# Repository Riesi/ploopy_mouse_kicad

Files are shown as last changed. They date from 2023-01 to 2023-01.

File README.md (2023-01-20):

# DISCLAIMER
## How was this ported to KiCAD?

The heavy lifting was done by the [altium2kicad](https://github.com/thesourcerer8/altium2kicad) converter. If you like this port do consider donating to the converter project!

After that I took the converted files and pruned unnecessary ones. Then I fixed the schematics by replacing the broken symbols with either existing ones or created custom symbols.
All components have been named as they appear in the PCB to allow for relinking of the footprints with the `Update Schematic from PCB` option in eeschema.
Finally I fixed the DRC errors generated in the PCB (default design rule settings). This meant fixing the broken edge cut lines, due to the converter creating non closed and not fully connected lines. It also sprinkled some edge cut dots over the lines, which was not that easy to find!

### Can I use this port instead of the main project?

I don't think anything speaks against using this KiCAD version. But be warned that I haven't produced a PCB with it myself! So things could be broken!
If you just want a working PCB you should use Gerber files produced from the original version instead.

If you want to help verifying the design please do so!

### Current Validation

Validation has been done with the `Gerbv` tool, which allows to compare two Gerber files and show their difference/overlap.
The files used for the validation are located in `./gerber_diff_view`. You can run the `diff_gerber.sh` to verify some of the Gerber files yourself. Be sure to generate the KiCAD Gerber in the following path `hardware/electronics/QMKMouse/gerber/` before running the script. There are also comparison shots of some layers in which the white corresponds to KiCAD, green to Altium and purple to the matching XOR of both.

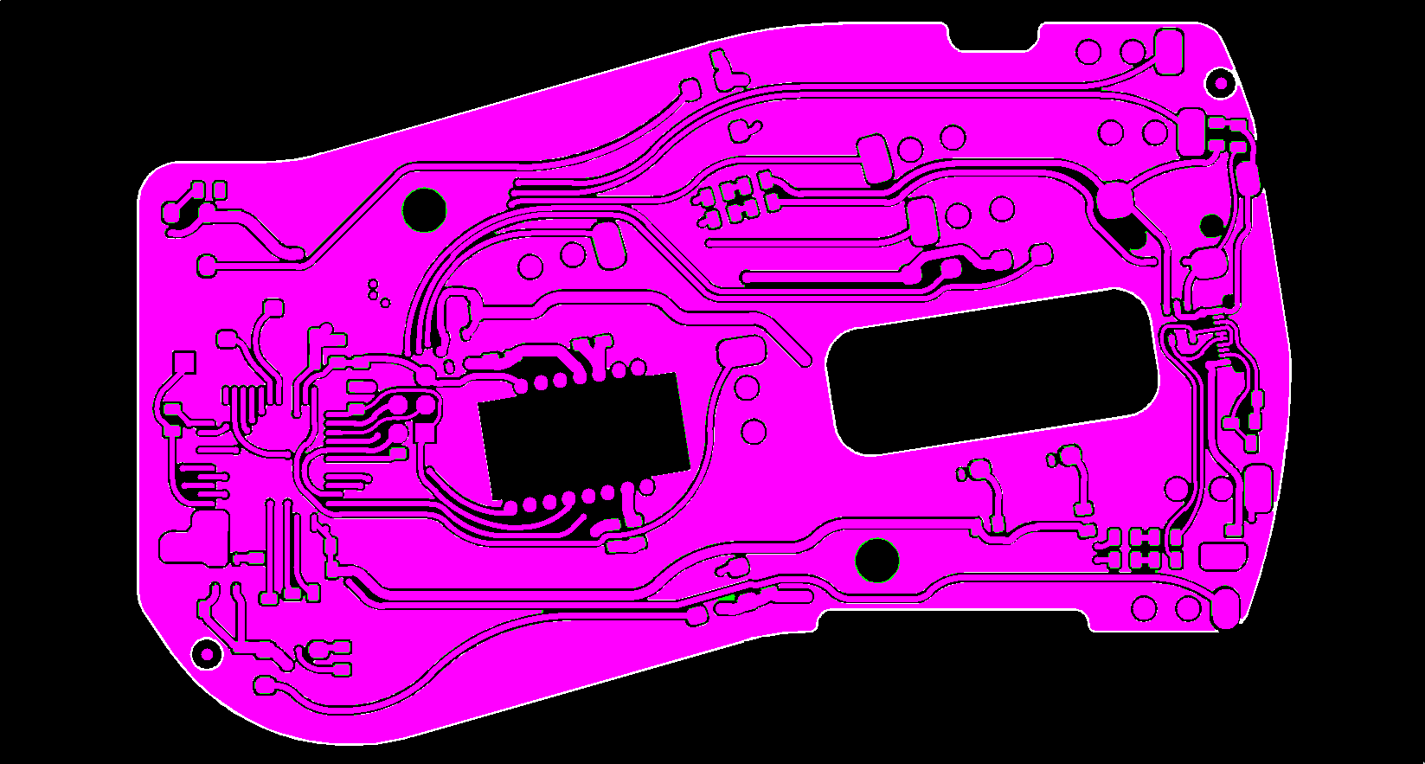
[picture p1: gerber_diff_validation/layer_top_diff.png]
Diff of top layers


#### Labels:

Text is different due to fonts.
Drawings look correct.

#### Layers:

Only minimal difference due to difference in clearance to the border cut and filling algorithm.
KiCAD version has a bit more portions filled. This should not be an issue.

#### Edge Cuts:

Match.

#### Drill:
Drill holes look correct.
Mismatch on some holes that are not plated in the fabricated PCB, but Altium files still contain them as plated.
Should be no problem.

#### Drill Maps:
No drill mapped to optical sensor in KiCAD, but this should not be an issue.

#### Masks:

Match.

#### Pastes:

Match.

# The Ploopy Mouse

By some stroke of luck, you've made your way here. The Ploopy Mouse. Your life will never be the same.

This repository contains all of the design and production files necessary to make a Ploopy Mouse. We've also included some kick-ass documentation in the Wiki on how to get it made, assemble it, and program it.

What are you waiting for? Your new life awaits.

## QMK?!

Kits bought from the [Ploopy store](https://ploopy.co/product-category/mouse/) come with QMK preloaded. Check out the Wiki for instructions on how to load new firmware onto your device. (It's super easy!)

The firmware hex file that ships with all Mice is included in this repository as well, as `ploopyco_mouse_via.hex`. The hex was built with QMK version 0.11.1.

## Under what license is this released?

Everything in this repository is released under OHL CERN v2-S. Check the LICENSE.md file for full license text.

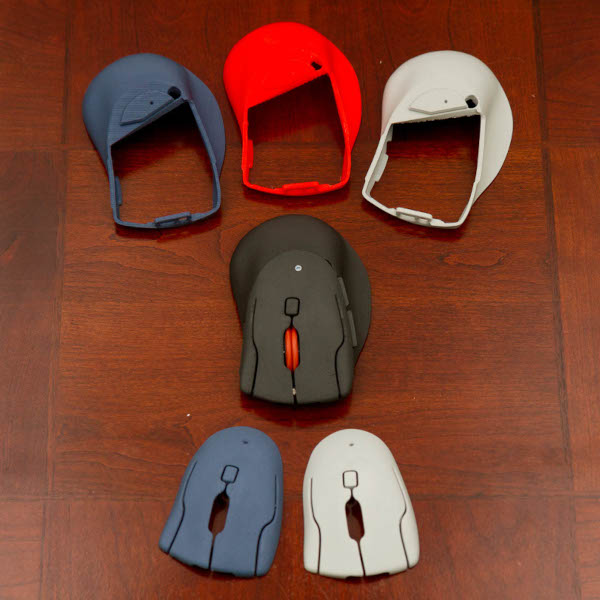
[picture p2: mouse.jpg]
The Ploopy Mouse


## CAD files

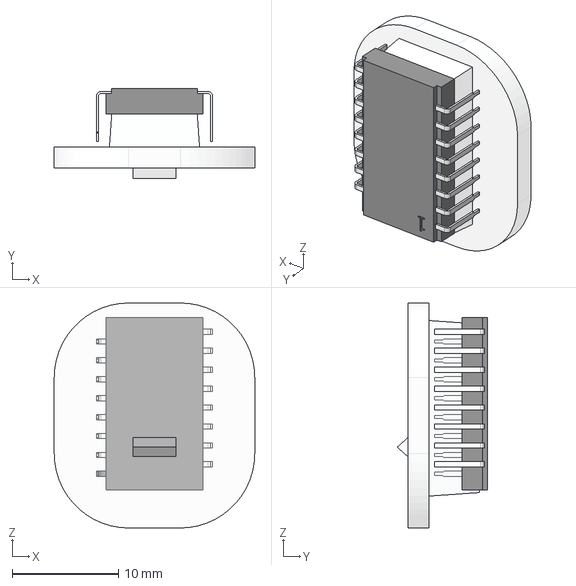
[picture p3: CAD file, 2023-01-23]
hardware/electronics/QMKMouse/ALTIUM_EMBEDDED_MODELS/PMW3360-LM19-LSI-Assembly.stp
18.8 x 8.50 x 21.1 mm
LM19-LSI
PMW3360DM-T2QU

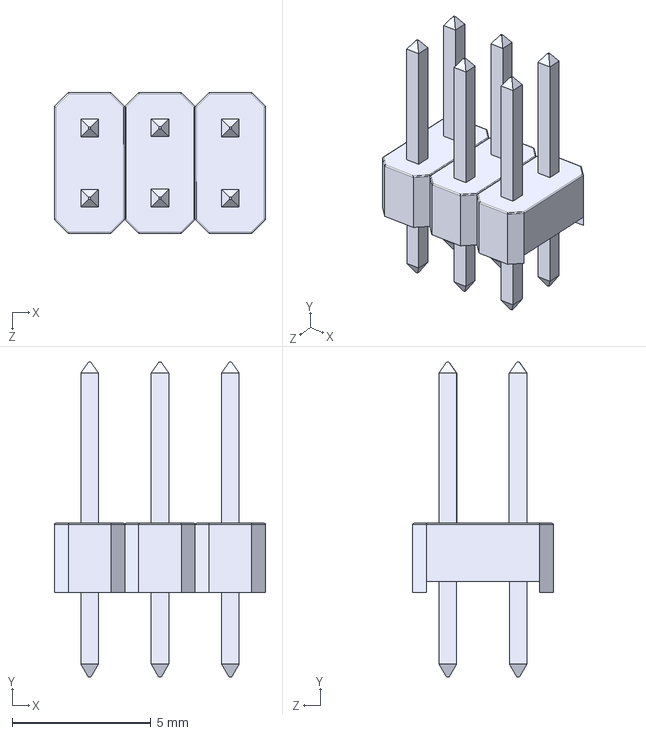
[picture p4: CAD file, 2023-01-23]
hardware/electronics/QMKMouse/ALTIUM_EMBEDDED_MODELS/PR(E,P)C003DAAN-RC.stp
7.62 x 11.4 x 5.08 mm
Dual TH with end bump format x 3

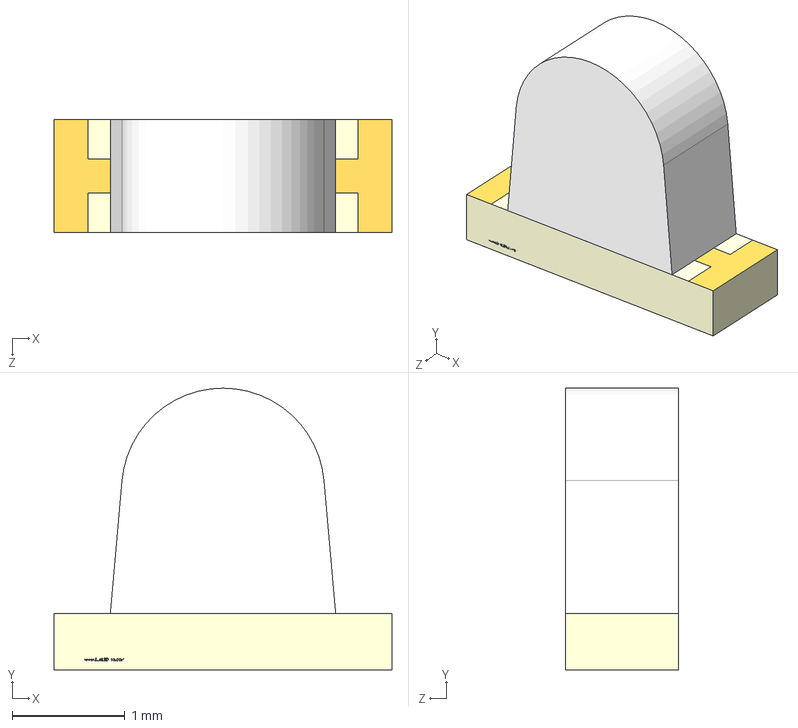
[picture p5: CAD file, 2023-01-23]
hardware/electronics/QMKMouse/ALTIUM_EMBEDDED_MODELS/XZxx56x-1.step
3.00 x 2.50 x 1.00 mm

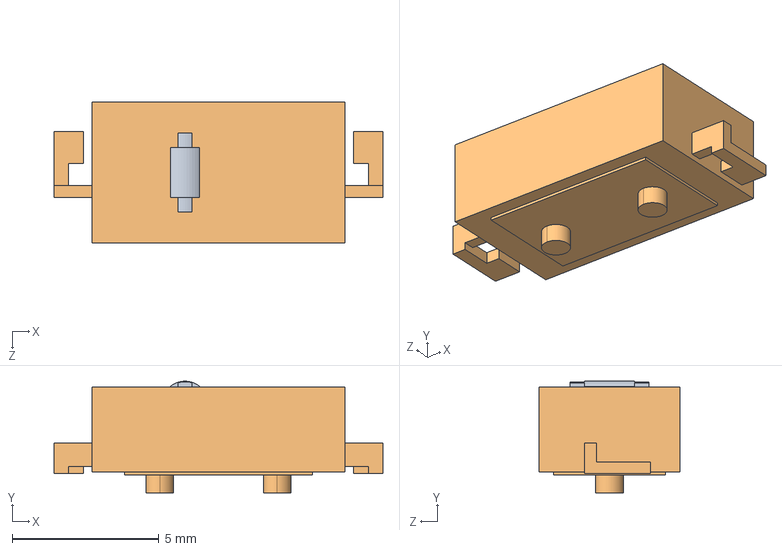
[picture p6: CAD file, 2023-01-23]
hardware/electronics/QMKMouse/ALTIUM_EMBEDDED_MODELS/D2LS_21.step
11.2 x 3.80 x 4.80 mm
D2LS_21_BUTTON
D2LS_21_BASE

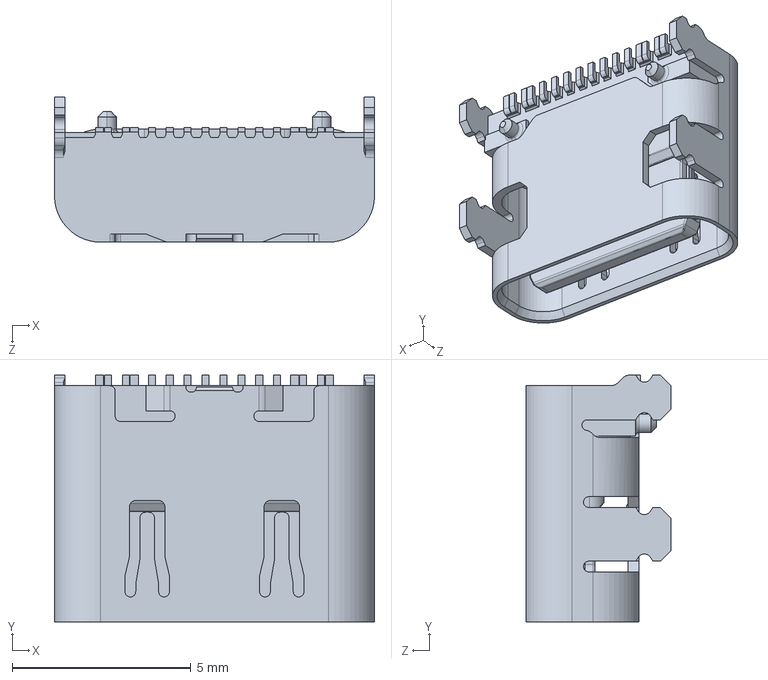
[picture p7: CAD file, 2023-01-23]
hardware/electronics/QMKMouse/ALTIUM_EMBEDDED_MODELS/K3D-DX07S016JA1-V1_JAE_Proprietary.STEP
8.94 x 6.90 x 4.06 mm

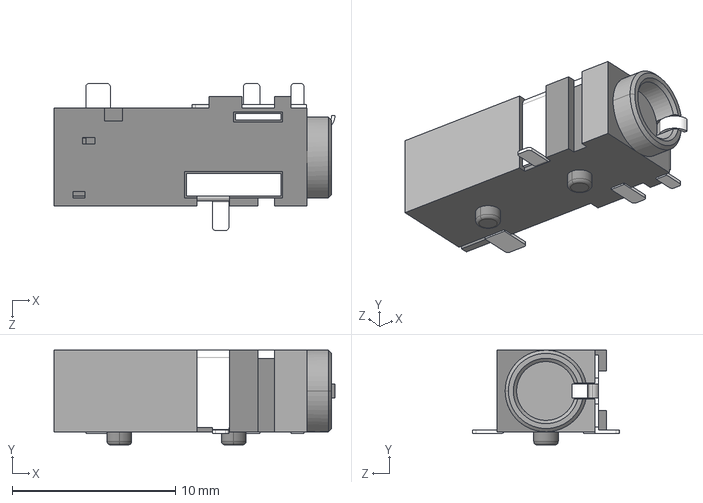
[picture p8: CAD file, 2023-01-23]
hardware/electronics/QMKMouse/ALTIUM_EMBEDDED_MODELS/CUI_DEVICES_SJ-43514-SMT-TR.step
17.2 x 5.80 x 9.00 mm

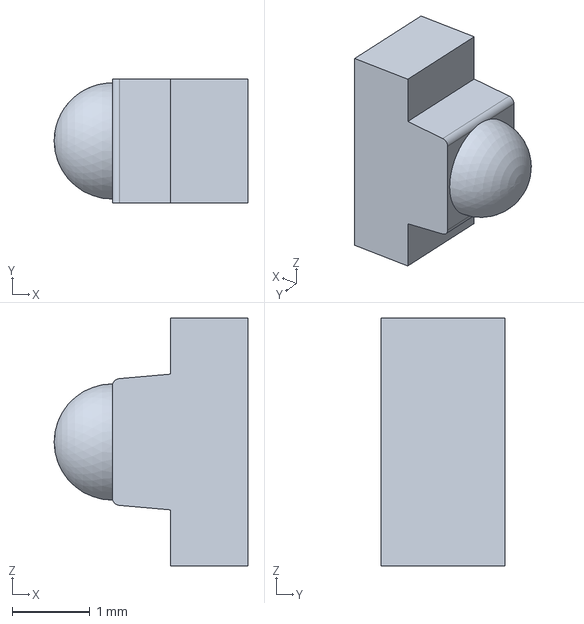
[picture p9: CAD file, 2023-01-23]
hardware/electronics/QMKMouse/ALTIUM_EMBEDDED_MODELS/PT26-51B-TR8.stp
2.50 x 1.60 x 3.20 mm

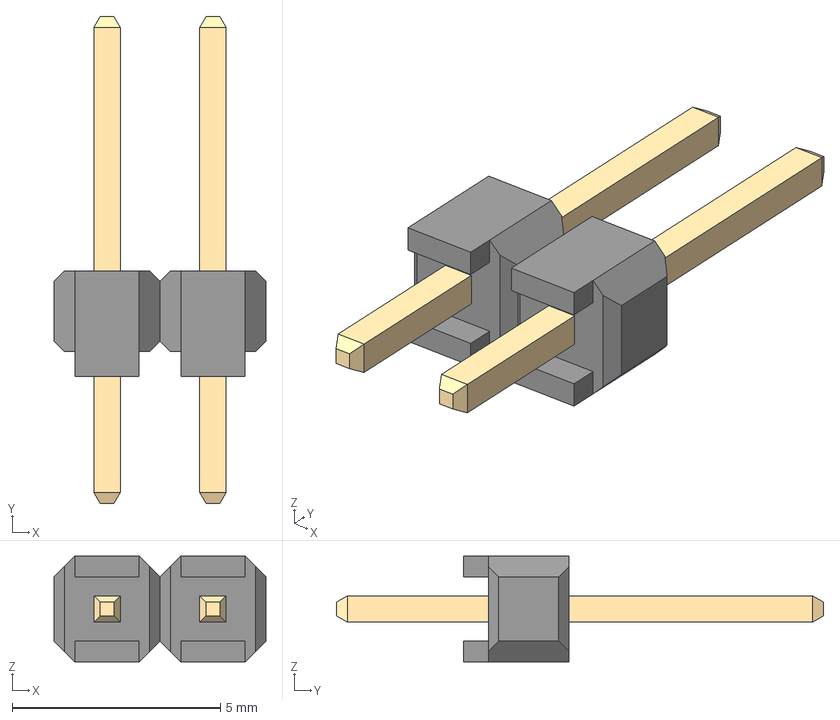
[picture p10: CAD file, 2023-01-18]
hardware/electronics/QMKMouse/ALTIUM_EMBEDDED_MODELS/m20-9990245_asm.stp
5.08 x 11.7 x 2.54 mm
M20-999-MOULD
M20-999-PIN x 2

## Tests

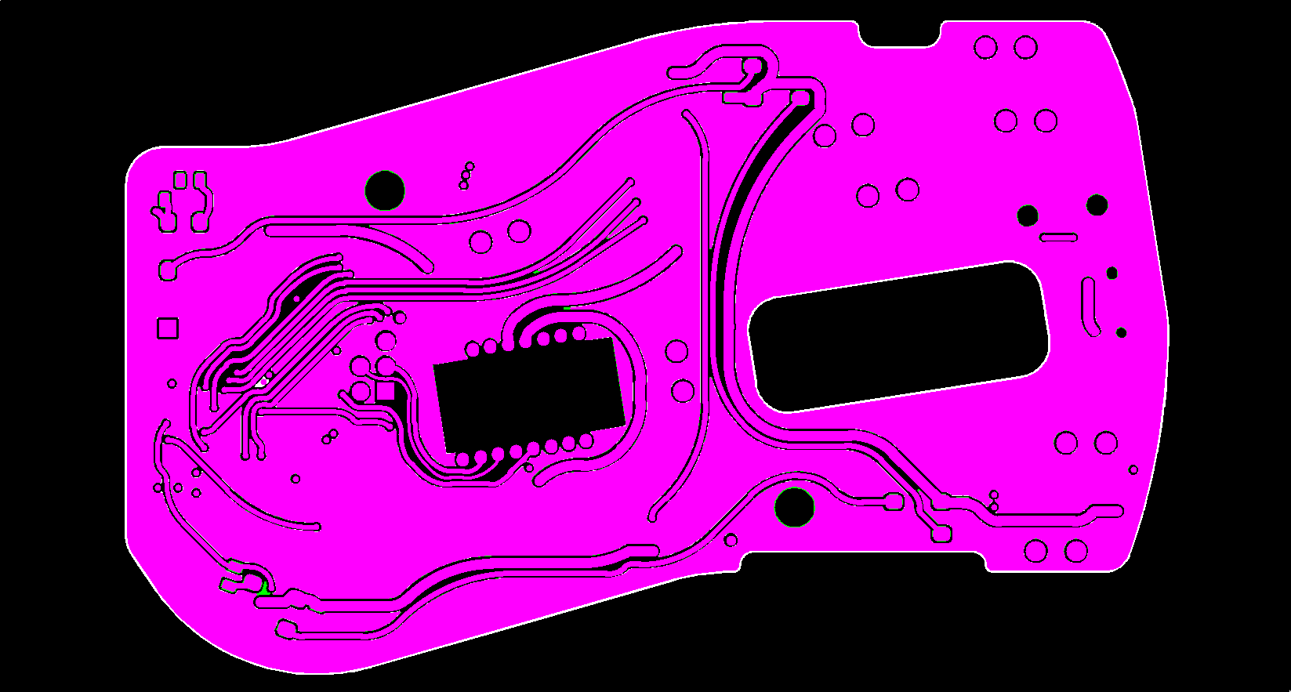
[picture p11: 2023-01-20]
gerber_diff_validation/layer_bot_diff.png

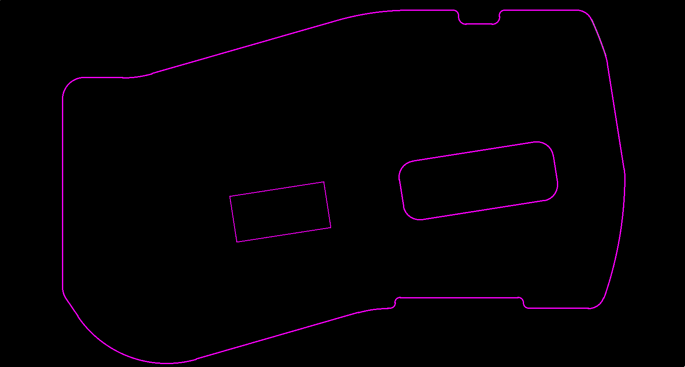
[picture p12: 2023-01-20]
gerber_diff_validation/edge_cuts_diff.png

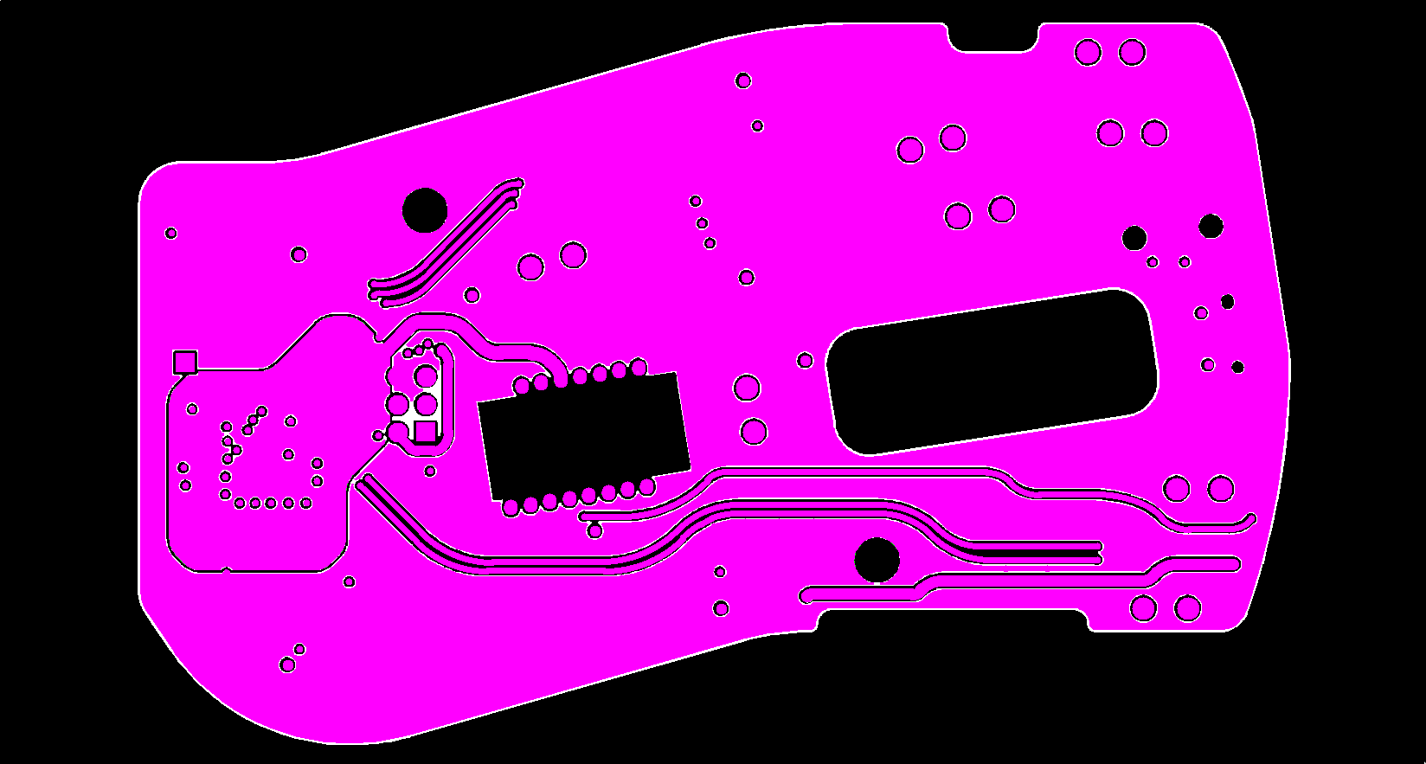
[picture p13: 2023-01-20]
gerber_diff_validation/layer_2_diff.png

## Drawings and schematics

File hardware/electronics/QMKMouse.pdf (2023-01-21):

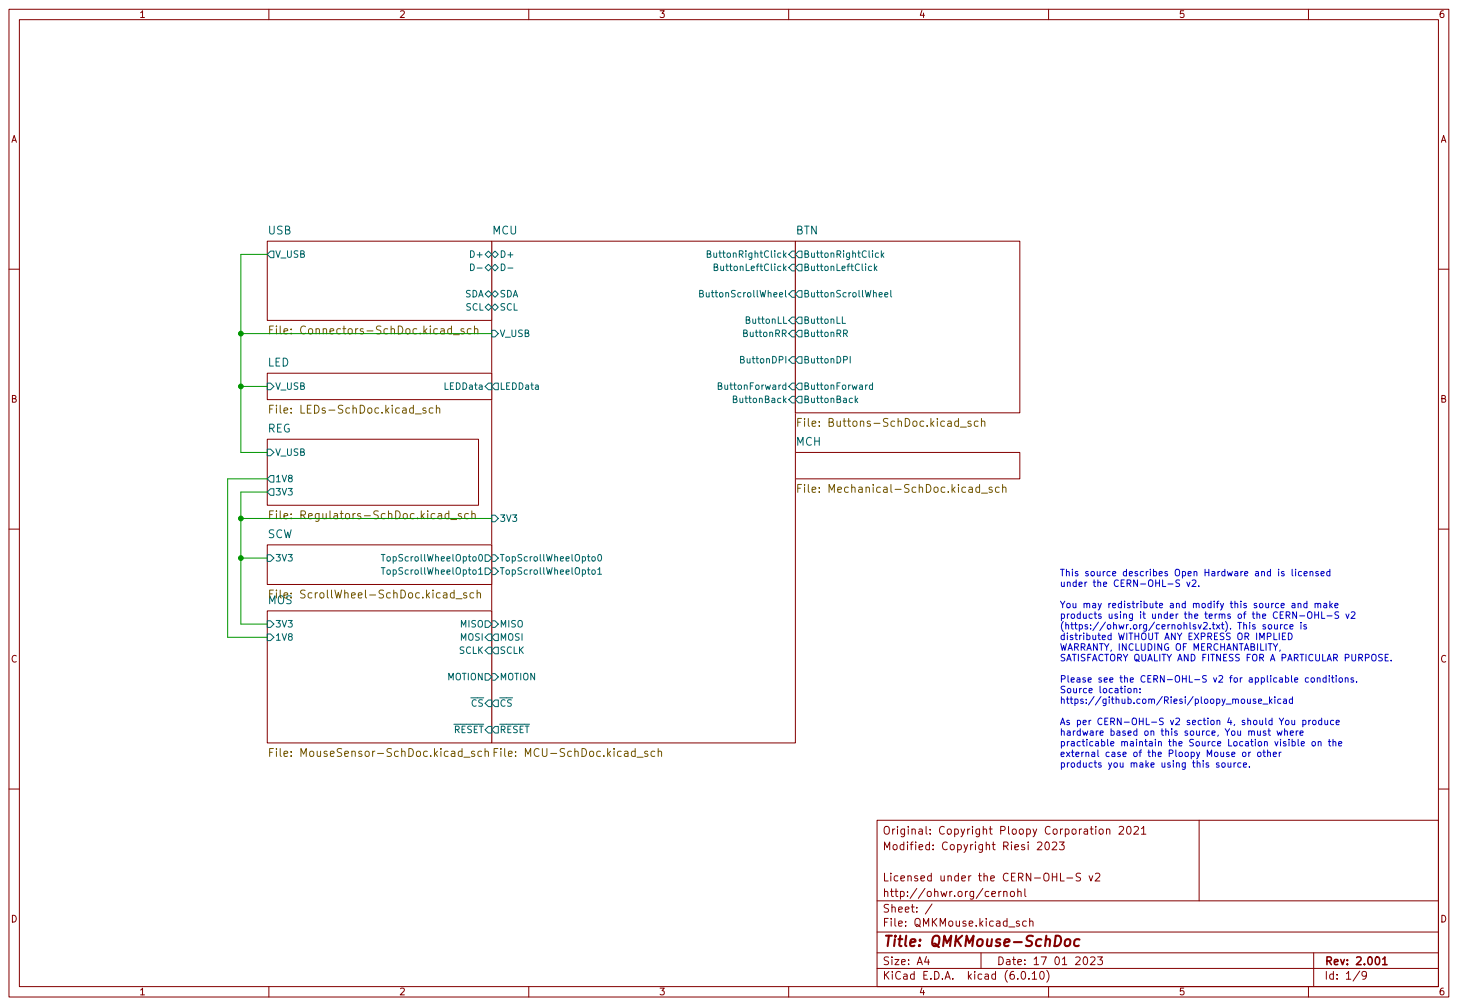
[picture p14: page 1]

ButtonLL BTN
ButtonRightClick ButtonLeftClick ButtonBack ButtonForward ButtonScrollWheel ButtonDPI ButtonRR

File: Buttons-SchDoc.kicad_sch
Licensed under the CERN-OHL-S v2 MCH

This source describes Open Hardware and is licensed under the CERN-OHL-S v2. You may redistribute and modify this source and make

products using it under the terms of the CERN-OHL-S v2
(https://ohwr.org/cernohlsv2.txt). This source is distributed WITHOUT ANY EXPRESS OR IMPLIED WARRANTY, INCLUDING OF MERCHANTABILITY, SATISFACTORY QUALITY AND FITNESS FOR A PARTICULAR PURPOSE. Please see the CERN-OHL-S v2 for applicable conditions. Source location: https://github.com/Riesi/ploopy_mouse_kicad

As per CERN-OHL-S v2 section 4, should You produce hardware based on this source, You must where practicable maintain the Source Location visible on the

external case of the Ploopy Mouse or other
products you make using this source.

Original: Copyright Ploopy Corporation 2021
Modified: Copyright Riesi 2023

File: QMKMouse.kicad_sch Sheet: / http://ohwr.org/cernohl

Id: 1/9 Title: QMKMouse-SchDoc

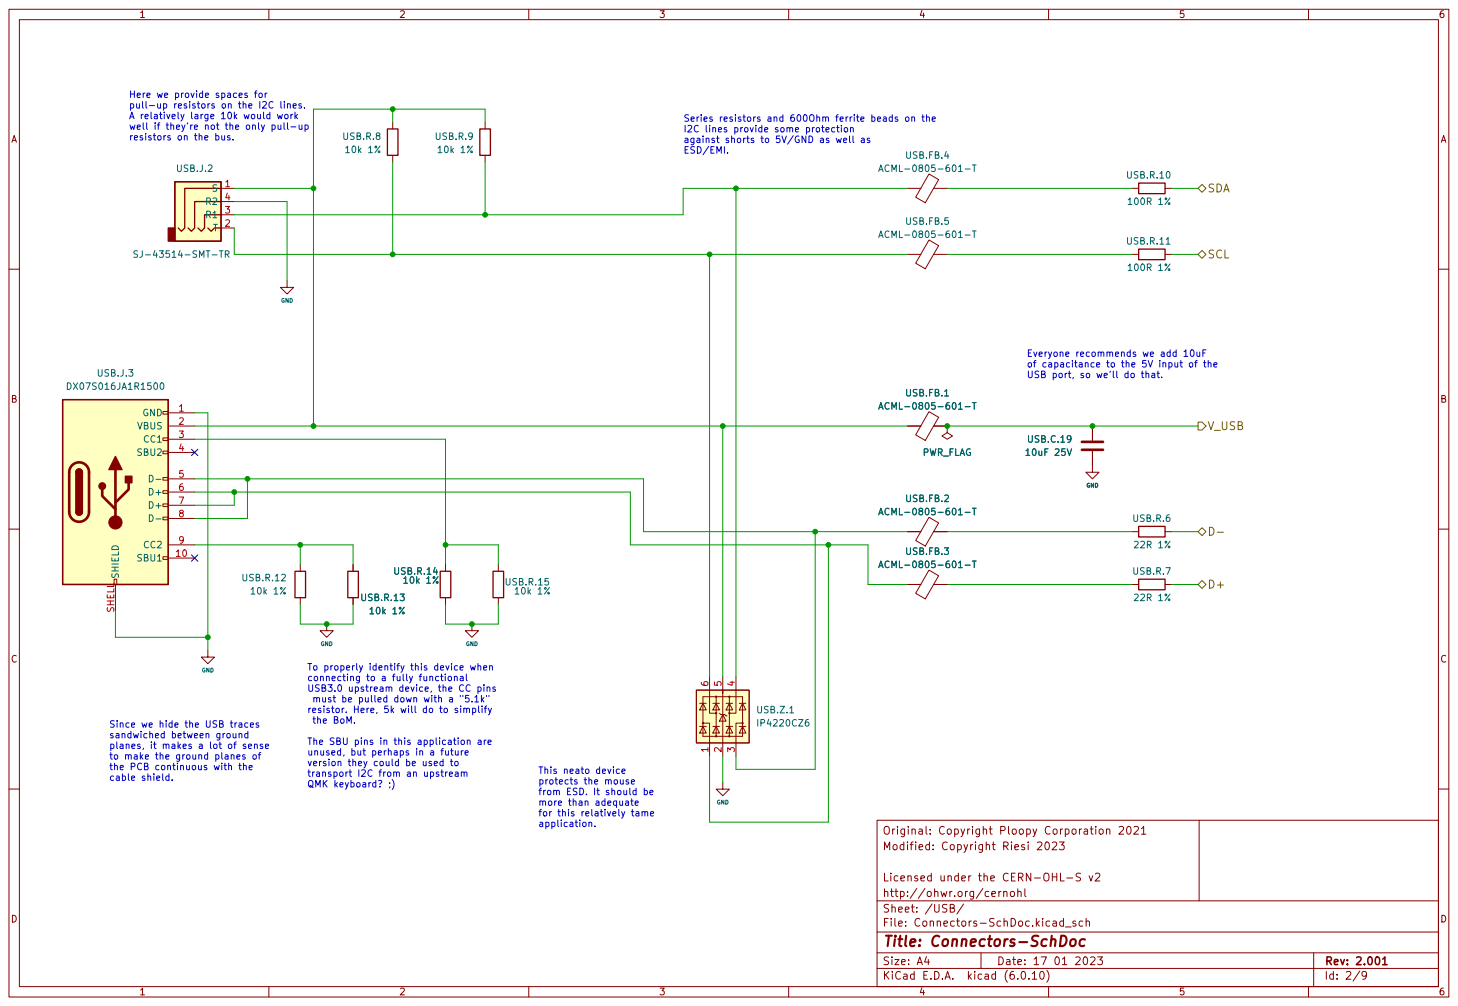
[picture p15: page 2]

against shorts to 5V/GND as well as ESD/EMI. Here we provide spaces for
pull-up resistors on the I2C lines.
A relatively large 10k would work

Series resistors and 600Ohm ferrite beads on the
I2C lines provide some protection

SCL D+D- Everyone recommends we add 10uF

of capacitance to the 5V input of the

USB port, so we'll do that. This neato device protects the mouse

USB.FB.1 ACML-0805-601-T USB.R.13

GND USB.FB.3 ACML-0805-601-T USB.FB.2 ACML-0805-601-T PWR_FLAG

10uF 25V USB.FB.3 ACML-0805-601-T USB.FB.2 ACML-0805-601-T PWR_FLAG

Licensed under the CERN-OHL-S v2 USB.R.12

To properly identify this device when
connecting to a fully functional
USB3.0 upstream device, the CC pins
must be pulled down with a "5.1k"
resistor. Here, 5k will do to simplify
the BoM. The SBU pins in this application are

QMK keyboard? ;) Since we hide the USB traces sandwiched between ground

planes, it makes a lot of sense
to make the ground planes of
the PCB continuous with the cable shield.

unused, but perhaps in a future
version they could be used to
transport I2C from an upstream

from ESD. It should be more than adequate

for this relatively tame
application.

Original: Copyright Ploopy Corporation 2021
Modified: Copyright Riesi 2023

File: Connectors-SchDoc.kicad_sch Sheet: /USB/ http://ohwr.org/cernohl

Id: 2/9 Title: Connectors-SchDoc

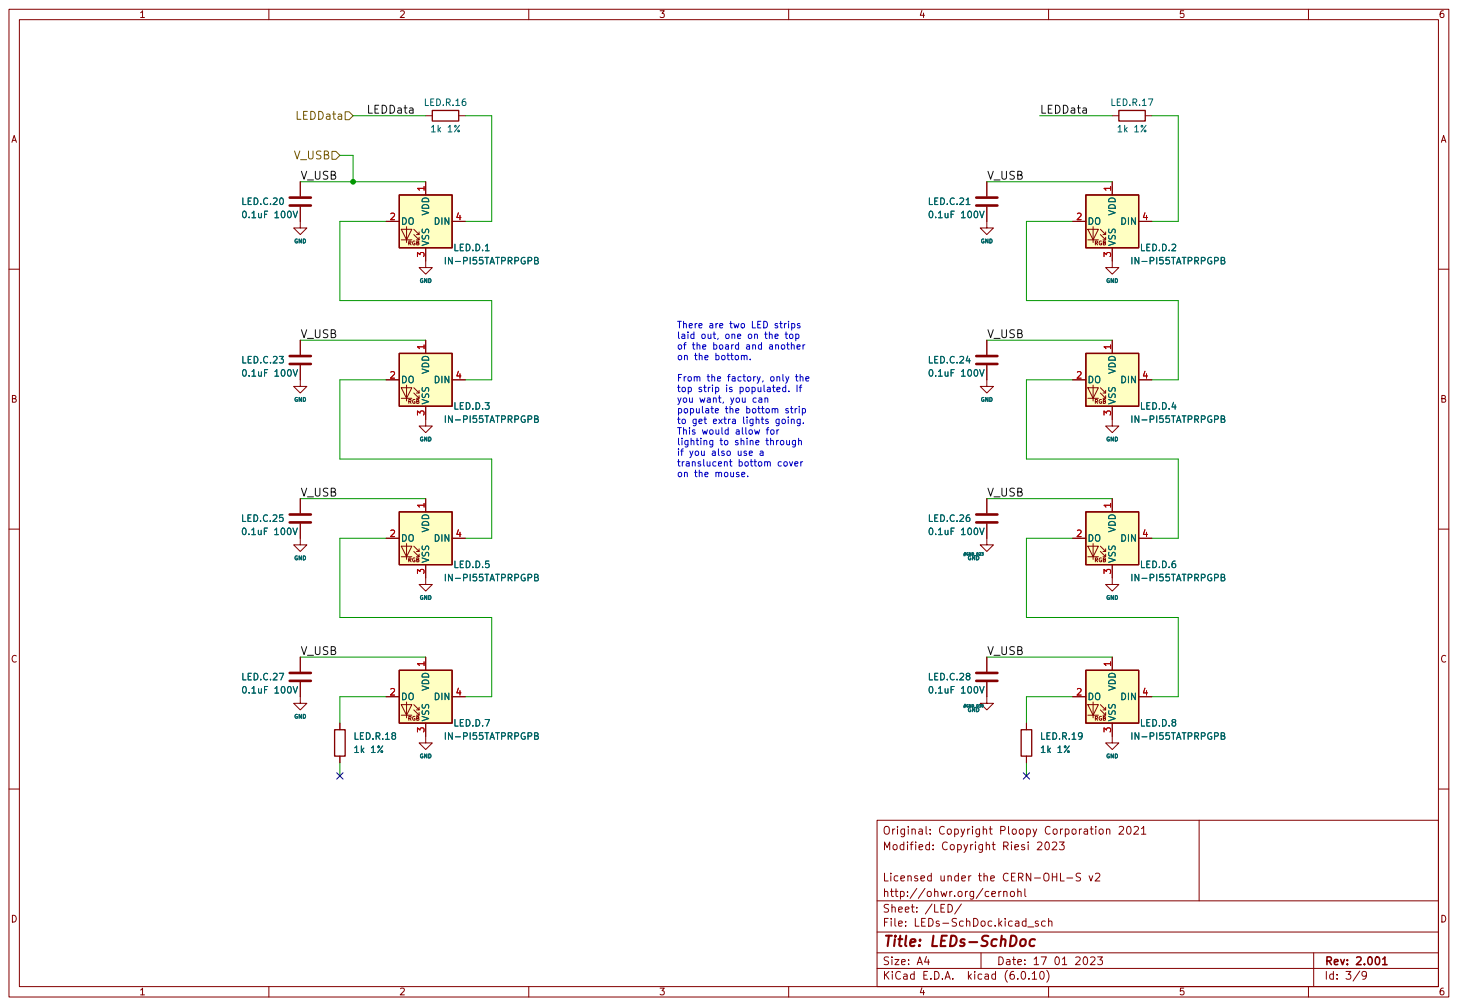
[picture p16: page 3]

There are two LED strips
laid out, one on the top of the board and another on the bottom. From the factory, only the

top strip is populated. If you want, you can populate the bottom strip

to get extra lights going. This would allow for

lighting to shine through
if you also use a

Original: Copyright Ploopy Corporation 2021
Modified: Copyright Riesi 2023

Licensed under the CERN-OHL-S v2
File: LEDs-SchDoc.kicad_sch Sheet: /LED/ http://ohwr.org/cernohl

Id: 3/9 Title: LEDs-SchDoc

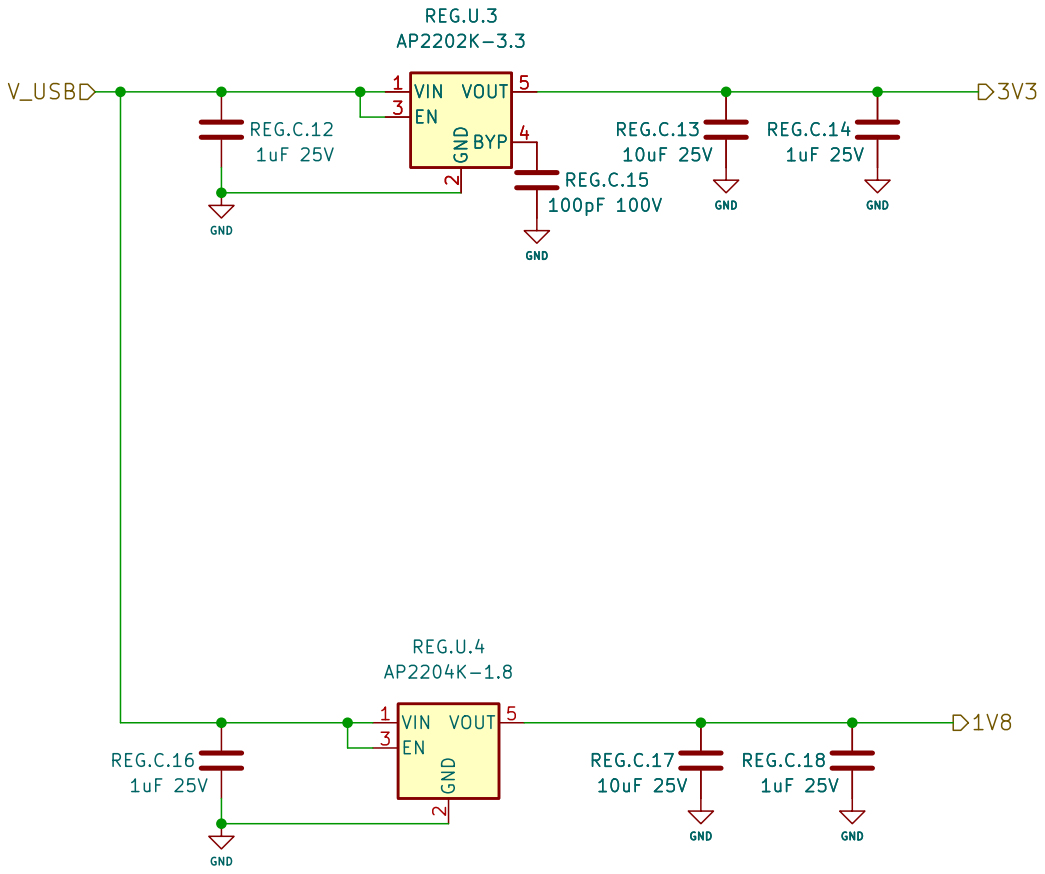
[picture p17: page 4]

2 EN 3 BYP 4 VOUT 5 REG.U.3 AP2202K-3.3 REG.C.15
GND REG.C.17

2 EN 3 VOUT 5 REG.U.4 AP2204K-1.8 REG.C.17

Original: Copyright Ploopy Corporation 2021
Modified: Copyright Riesi 2023

Licensed under the CERN-OHL-S v2
File: Regulators-SchDoc.kicad_sch Sheet: /REG/ http://ohwr.org/cernohl

Id: 4/9 Title: Regulators-SchDoc

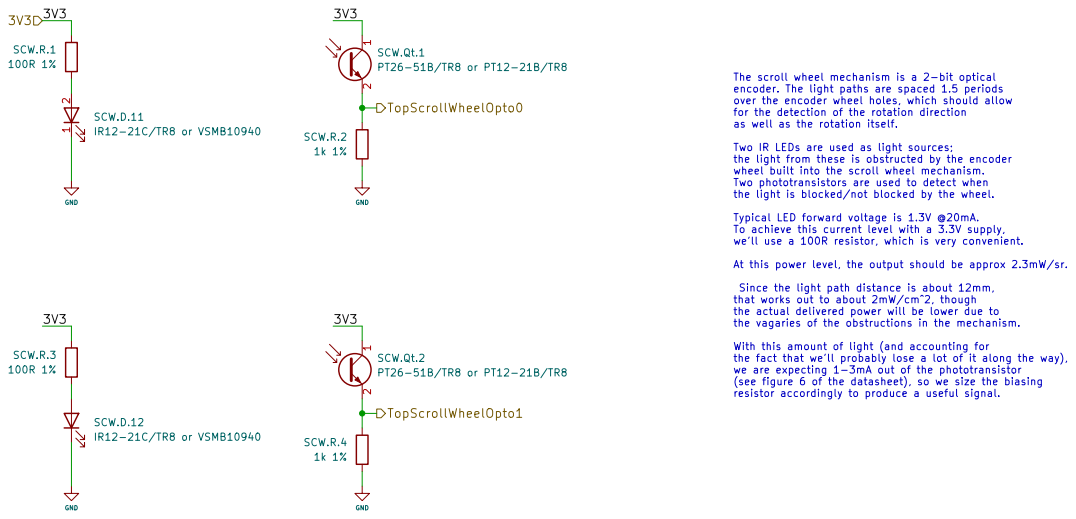
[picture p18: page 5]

1 2 SCW.Qt.1 PT26-51B/TR8 or PT12-21B/TR8 SCW.D.12

The scroll wheel mechanism is a 2-bit optical
encoder. The light paths are spaced 1.5 periods over the encoder wheel holes, which should allow

for the detection of the rotation direction as well as the rotation itself. Two IR LEDs are used as light sources;

the light from these is obstructed by the encoder wheel built into the scroll wheel mechanism. Two phototransistors are used to detect when

the light is blocked/not blocked by the wheel.

Typical LED forward voltage is 1.3V @20mA.
To achieve this current level with a 3.3V supply,
we'll use a 100R resistor, which is very convenient.

At this power level, the output should be approx 2.3mW/sr.

Since the light path distance is about 12mm,
that works out to about 2mW/cm^2, though
the actual delivered power will be lower due to
the vagaries of the obstructions in the mechanism.

With this amount of light (and accounting for
the fact that we'll probably lose a lot of it along the way),
we are expecting 1-3mA out of the phototransistor
(see figure 6 of the datasheet), so we size the biasing
resistor accordingly to produce a useful signal.
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

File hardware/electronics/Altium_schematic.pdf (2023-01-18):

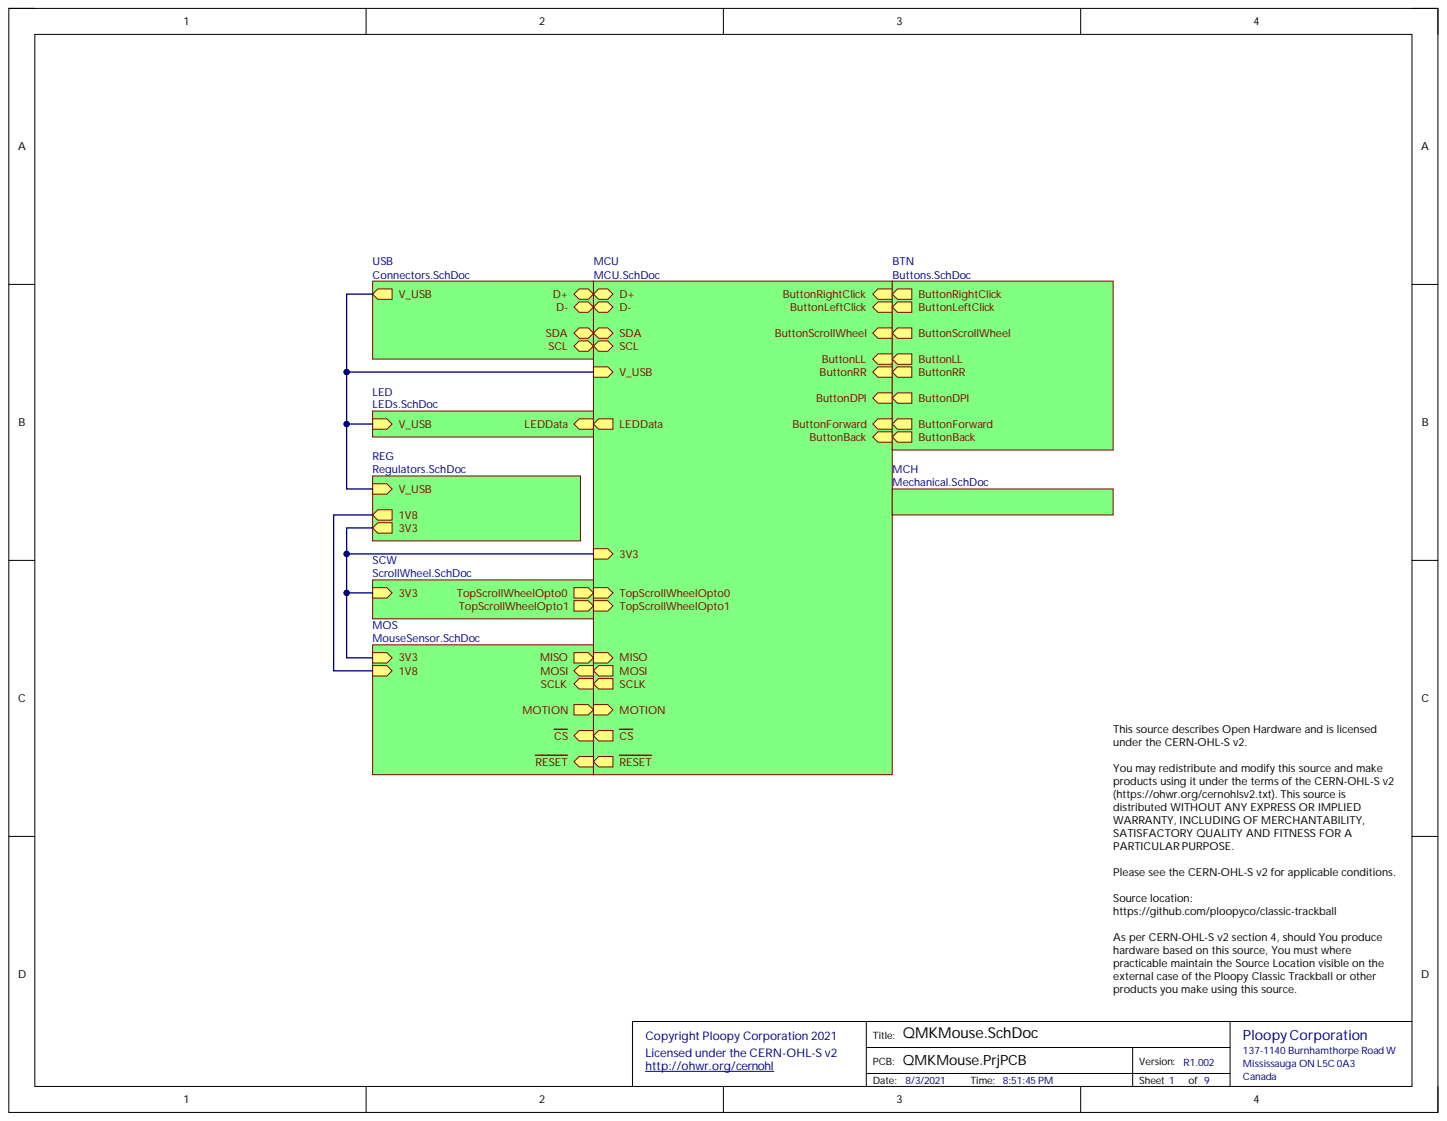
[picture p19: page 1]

This source describes Open Hardware and is licensed
under the CERN-OHL-S v2.

You may redistribute and modify this source and make
products using it under the terms of the CERN-OHL-S v2
(https://ohwr.org/cernohlsv2.txt). This source is
distributed WITHOUT ANY EXPRESS OR IMPLIED
WARRANTY, INCLUDING OF MERCHANTABILITY,
SATISFACTORY QUALITY AND FITNESS FOR A
PARTICULAR PURPOSE.

Please see the CERN-OHL-S v2 for applicable conditions.

Source location:
https://github.com/ploopyco/classic-trackball

As per CERN-OHL-S v2 section 4, should You produce
hardware based on this source, You must where
practicable maintain the Source Location visible on the
external case of the Ploopy Classic Trackball or other
products you make using this source.

Copyright Ploopy Corporation 2021
Licensed under the CERN-OHL-S v2
http://ohwr.org/cernohl

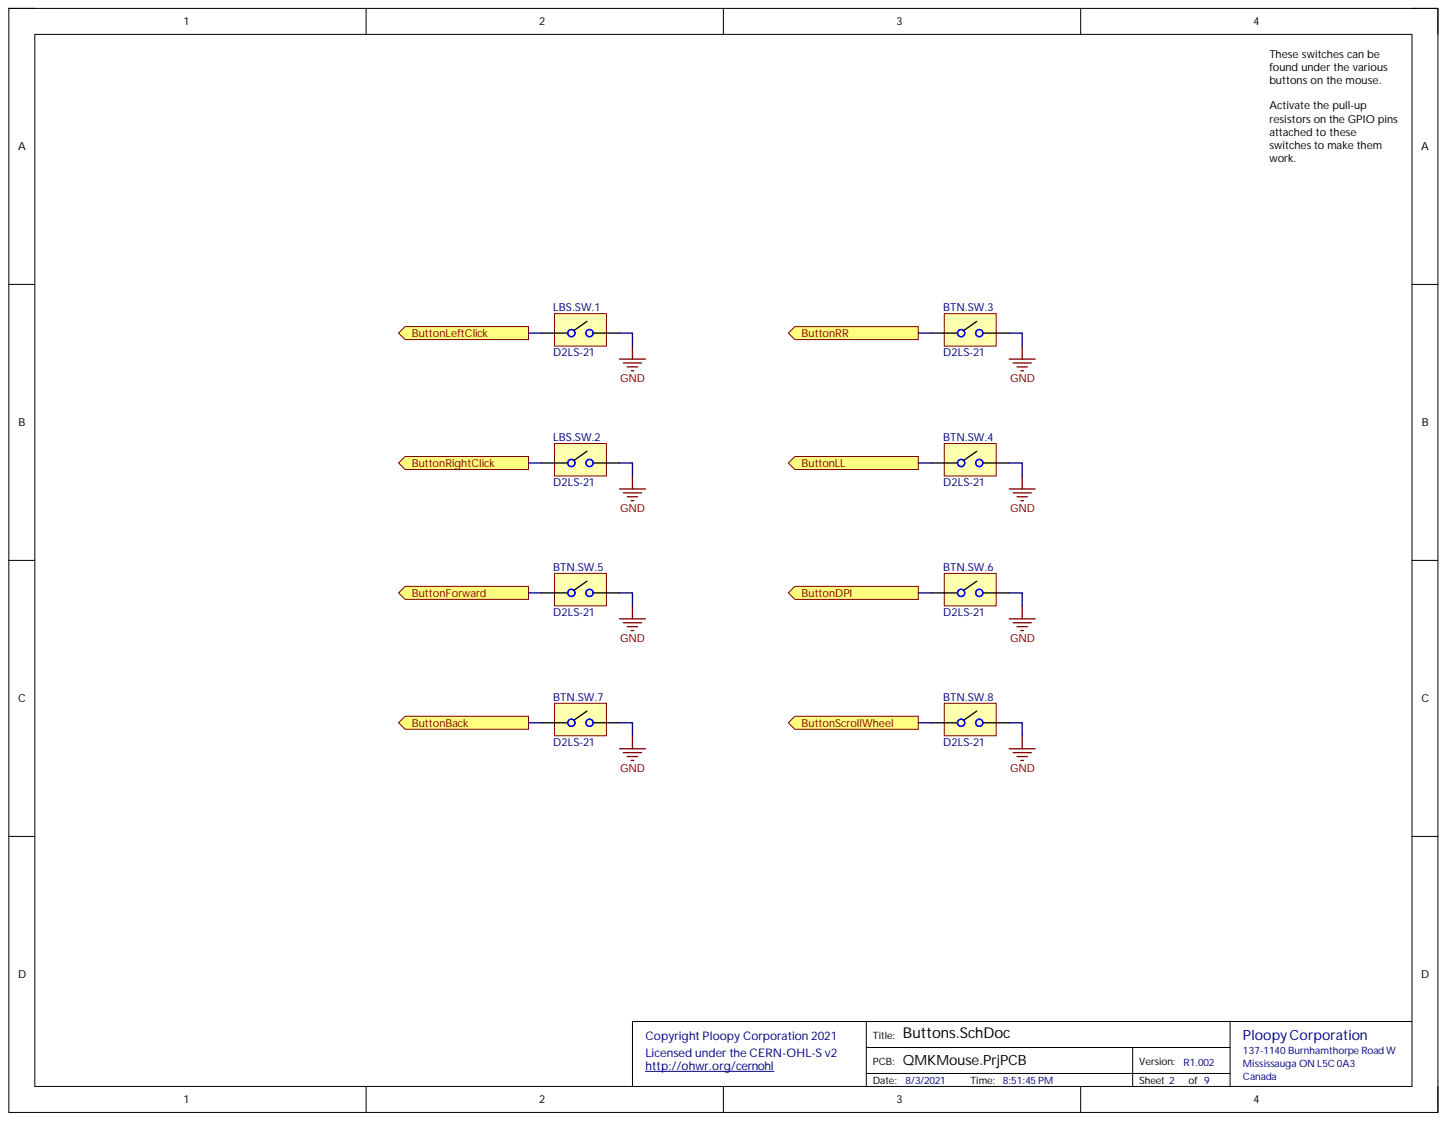
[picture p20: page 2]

These switches can be
found under the various
buttons on the mouse.

Activate the pull-up
resistors on the GPIO pins
attached to these
switches to make them
work.

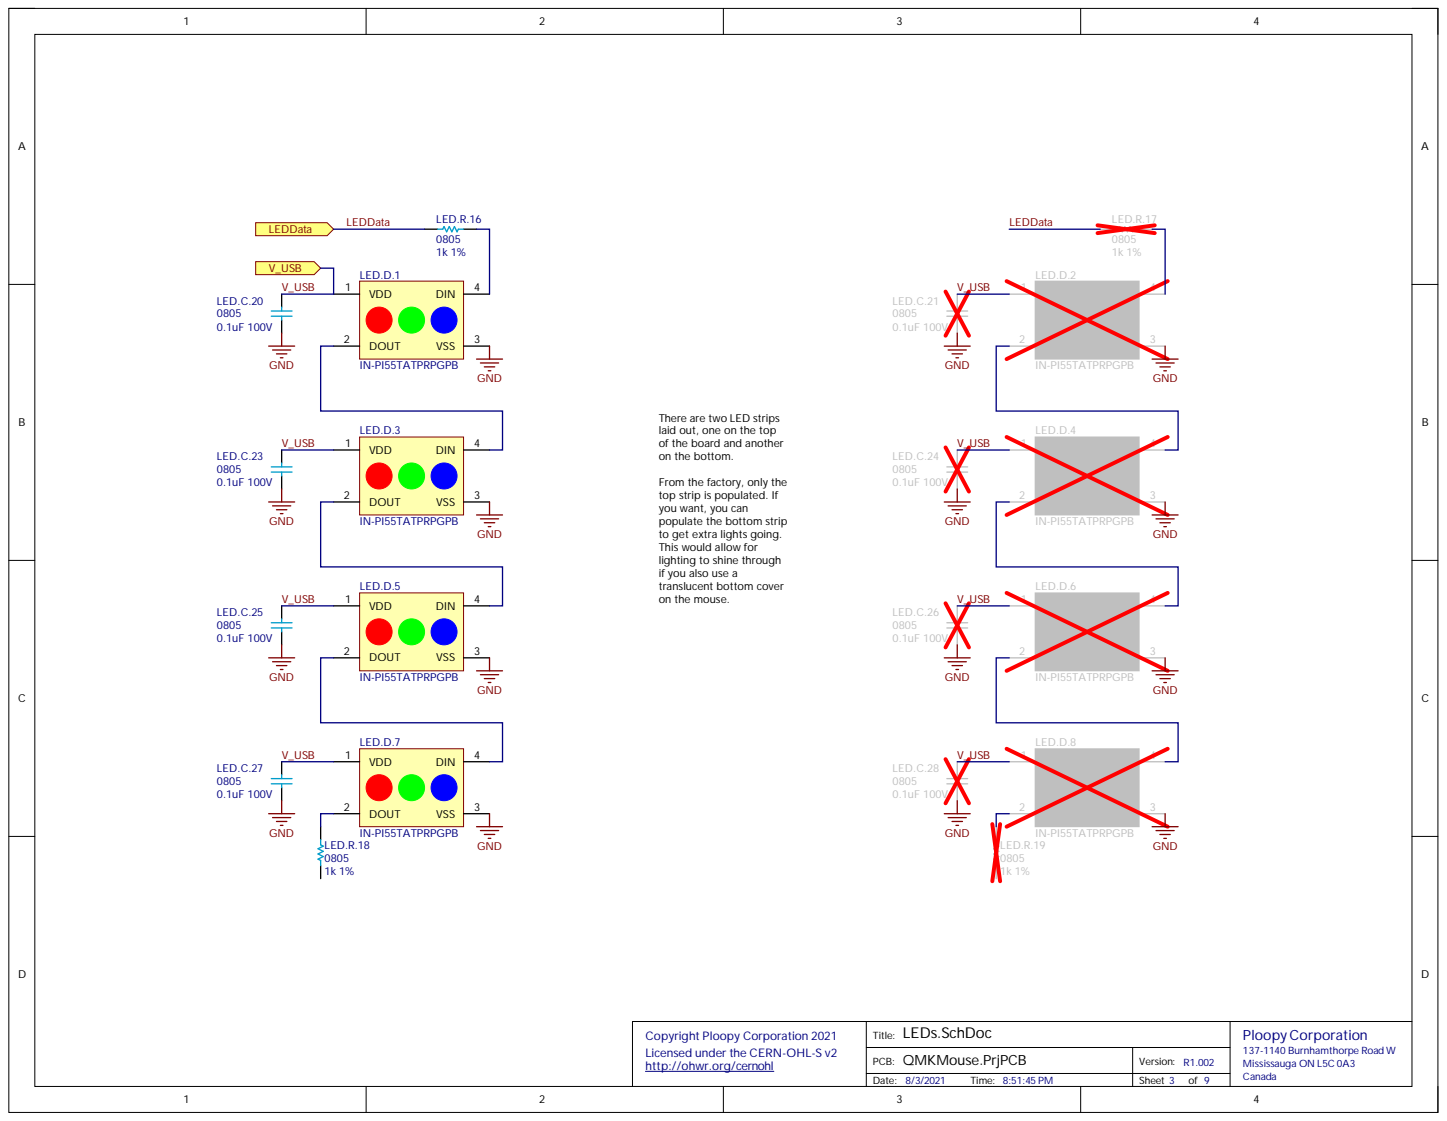
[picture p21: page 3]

There are two LED strips
laid out, one on the top
of the board and another
on the bottom.

From the factory, only the
top strip is populated. If
you want, you can
populate the bottom strip
to get extra lights going.
This would allow for
lighting to shine through
if you also use a
translucent bottom cover
on the mouse.

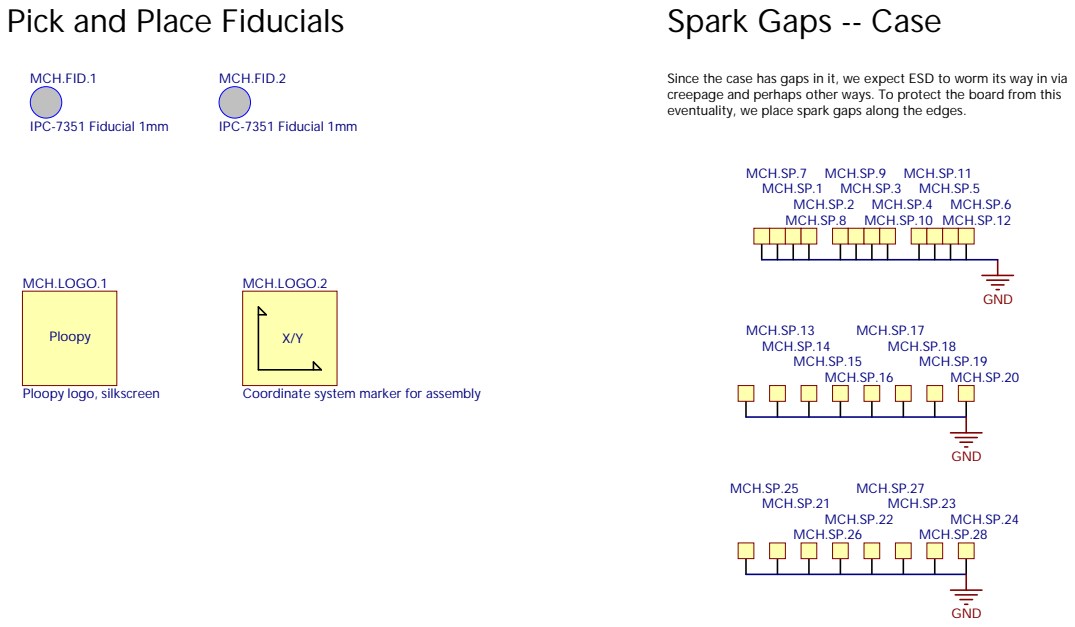
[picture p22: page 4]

Pick and Place Fiducials

Spark Gaps -- Case MCH.SP.7 MCH.SP.1 MCH.SP.8 MCH.SP.2 MCH.SP.9 MCH.SP.3 MCH.SP.10 MCH.SP.4 MCH.SP.1

Since the case has gap
creepage and perhap
eventuality, we place s

s other ways. To protect the board from this
park gap

pect ESD to worm its way in via

Coordinate system marker for assem

Cop
Licensed under the CE
http

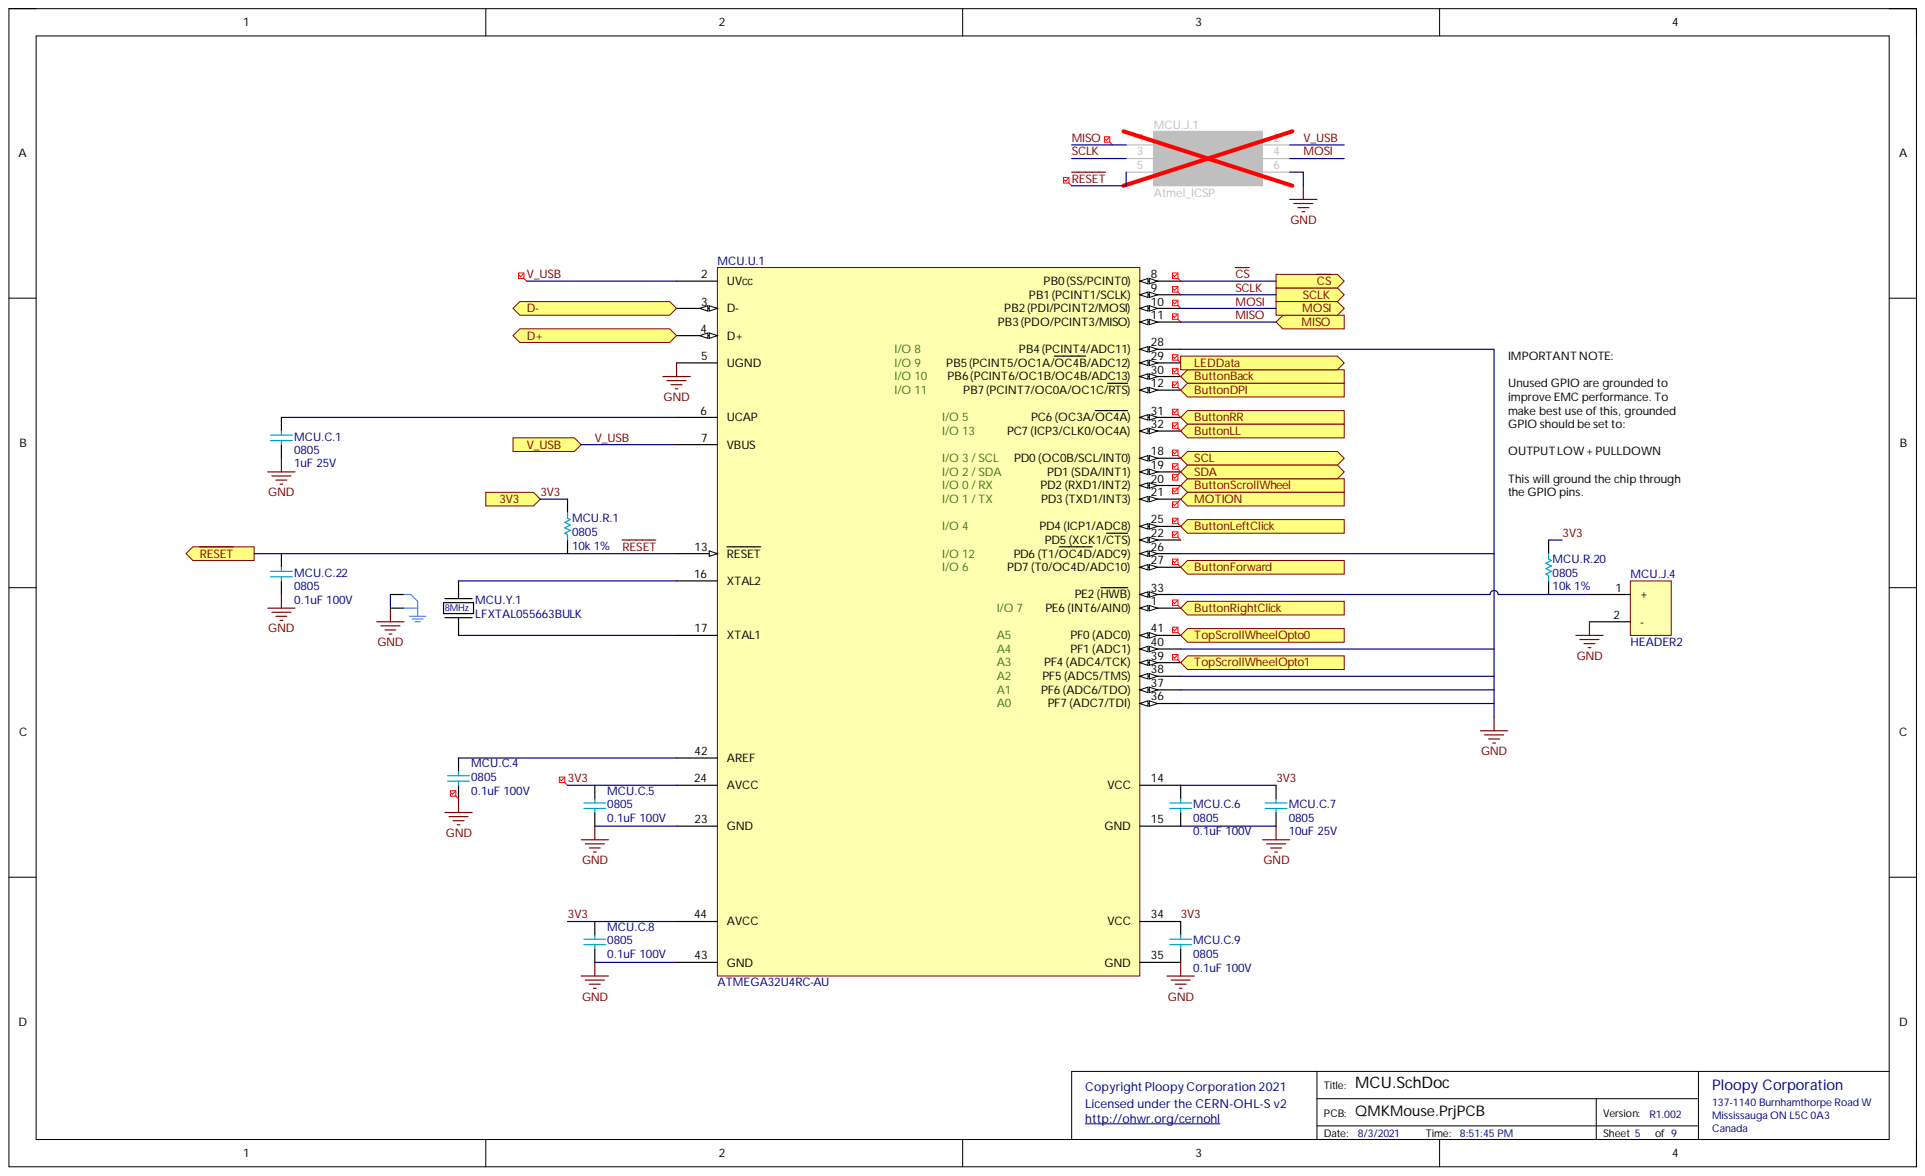
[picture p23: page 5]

best use of thi

C opy righ t Plo opy C o rpo ratio n 2 0 2 1 Lice n sed u nde r t h e CERN -O HL-S v 2 h t tp://o hwr.o rg/ce r n o h l | T i t le: MCU.SchDo c | Ploop y Corporation 137-1140 Burnha m tho rpe Ro ad W M i ss i ssauga ON L5C 0A 3 C anada

: QMKMouse.PrjPC B P C B | Vers i o n : R1.002

D a te: 8/3/2021 T i me: 8:51:45 P M | Sheet 5 o f 9

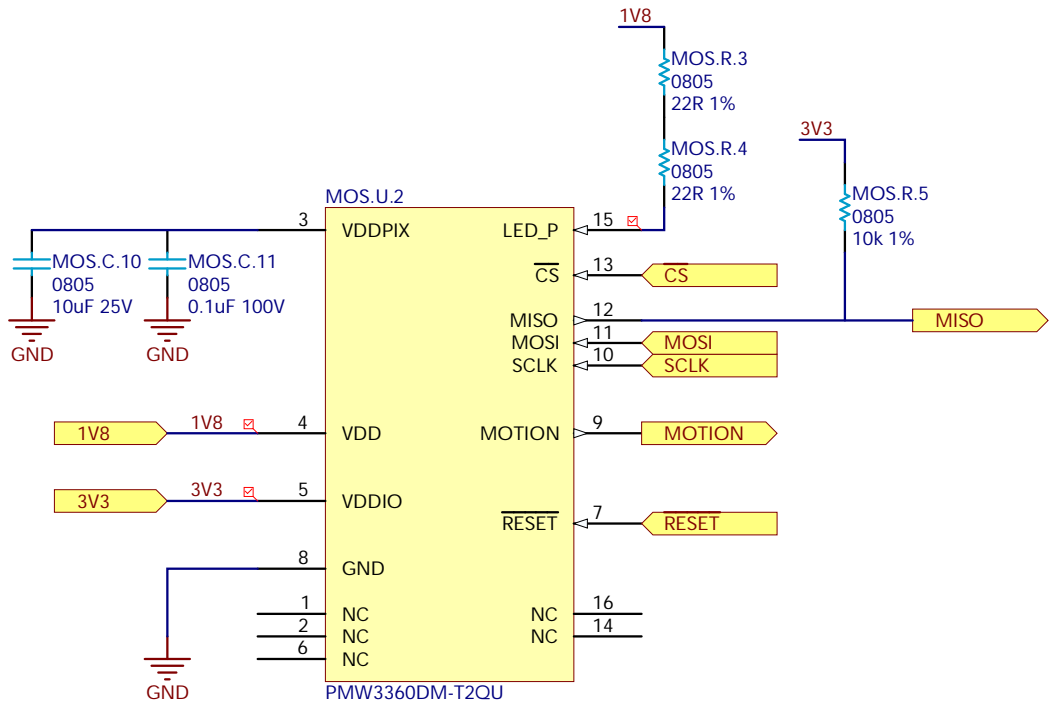
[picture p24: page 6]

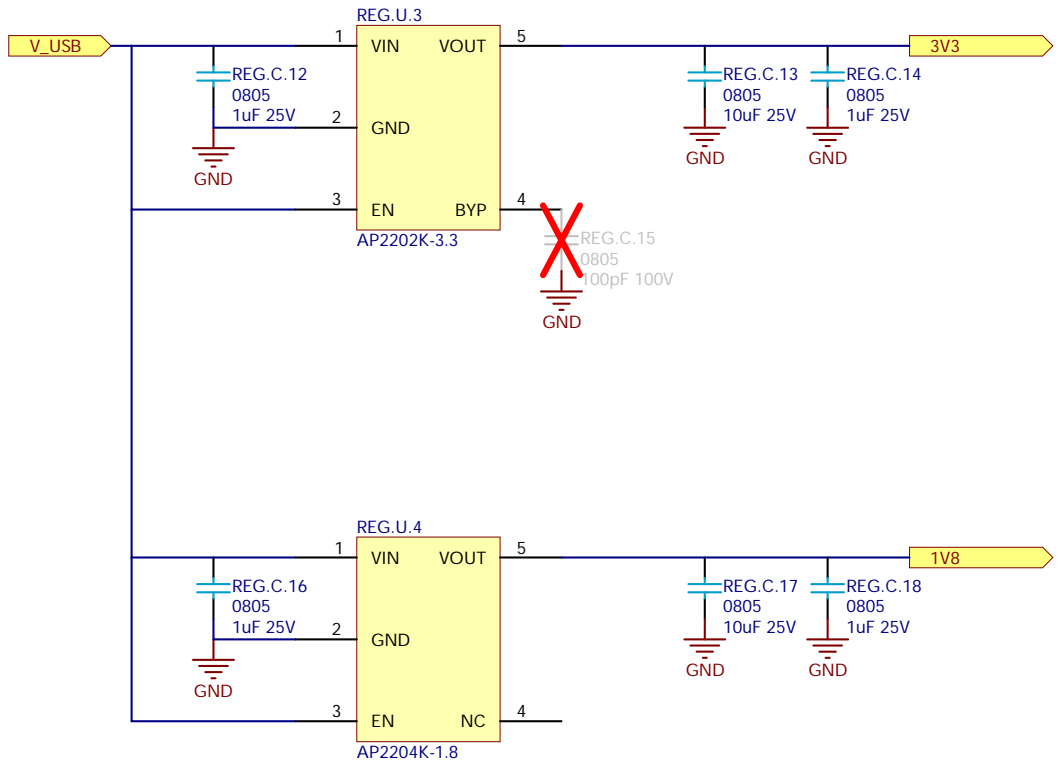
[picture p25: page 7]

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
## Ploopy

## Corporati

o

n

Mississauga ON

L5C 0A3

Sc

## rollWheel.SchDoc

R1.

8/3/202

1 | 8:51:45

P

M

Titl

e

:

Date

:

Versi

o

n

:

Ti

m

e

: | She e

t

o

f

PCB

:

## QMKMouse.Prj

P

C

B

Cop

yri

ght Ploop

y Corporation 2021
137-1140

Burnhamthorpe Ro

ad

W

Cana

d

a

Licensed under the CE

R

N

OHL-S

v
http

:

//ohwr.org

/ce

r

n

o

h

l

# TopScrollWheelOpto0 TopScrollWheelOpto1

SCW.Qt.

1
PT26-51B/T

R8 or PT12-21B/T

R

8

SCW.Qt.

2
PT26-51B/T

R8 or PT12-21B/T

R

8

The scroll wheel mechanis

m is a 2-

bit optical
encoder. The light paths are s

paced 1.5
period

s over the encoder wheel holes, which should allow for the detection of the rotation direction as well as the rotation itself. Two IR LEDs are used as light sources; the light

from these is ob

structed by the encoder wheel built into the scroll wheel mechanis

m. T

wo
phototransistors are used to

detect

when the
light is blocked/not blocked by the wheel. Typical LED forward voltage is 1.3V @20m

A.
To achieve this current level with a 3.3V sup

ply,
we'll use a 100R resistor, which is very convenient. At this power level, the output should be

ap

prox 2.3mW/sr.

Since the light path distance is about 12m

m,
that work

s out to about 2mW/cm

^2, though
the actual delivered power will be lower due to the vagaries of the ob

structions in the
mechanis

m

With this amount of light (and accounting for the fact that we'll probably lose a lot of it along the way), we are ex
pecting 1-3m

A out of
the phototransistor (see figure 6 of the datasheet), so we size the biasing resistor

accordingly to produce a useful signal.

100R 1%

SCW.R.1
0805

100R 1%

SCW.R.3
0805

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
1k 1%

SCW.R.2
0805

1k 1%

SCW.R.4
0805

G

N

D

3V

3

SCW.D.1

1
I

R12-21C/T

R8 or VSM

B10940

SCW.D.1

2
I

R12-21C/T

R8 or VSM

B10940


Here we provide s
pull-up resistors on the I2C lines. A relatively large 10k would work well if they're not the only pull-up

Series resistors and ferrite bead
I2C lines provide some protection against shorts to 5V/GND as well as ESD/EMI.

Everyone recom
capacitance to the 5V input of the USB port, so we'll do that.
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

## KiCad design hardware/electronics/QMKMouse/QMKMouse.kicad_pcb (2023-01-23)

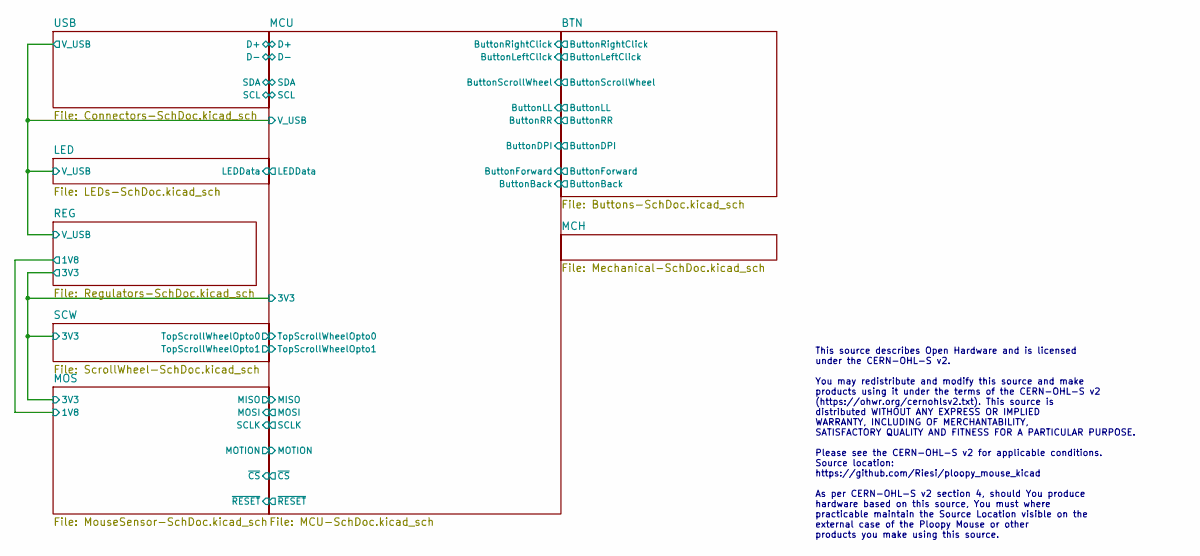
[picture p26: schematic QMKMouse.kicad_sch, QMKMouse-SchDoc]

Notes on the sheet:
This source describes Open Hardware and is licensed under the CERN-OHL-S v2. You may redistribute and modify this source and make products using it under the terms of the CERN-OHL-S v2 (https://ohwr.org/cernohlsv2.txt). This source is distributed WITHOUT ANY EXPRESS OR IMPLIED WARRANTY, INCLUDING O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

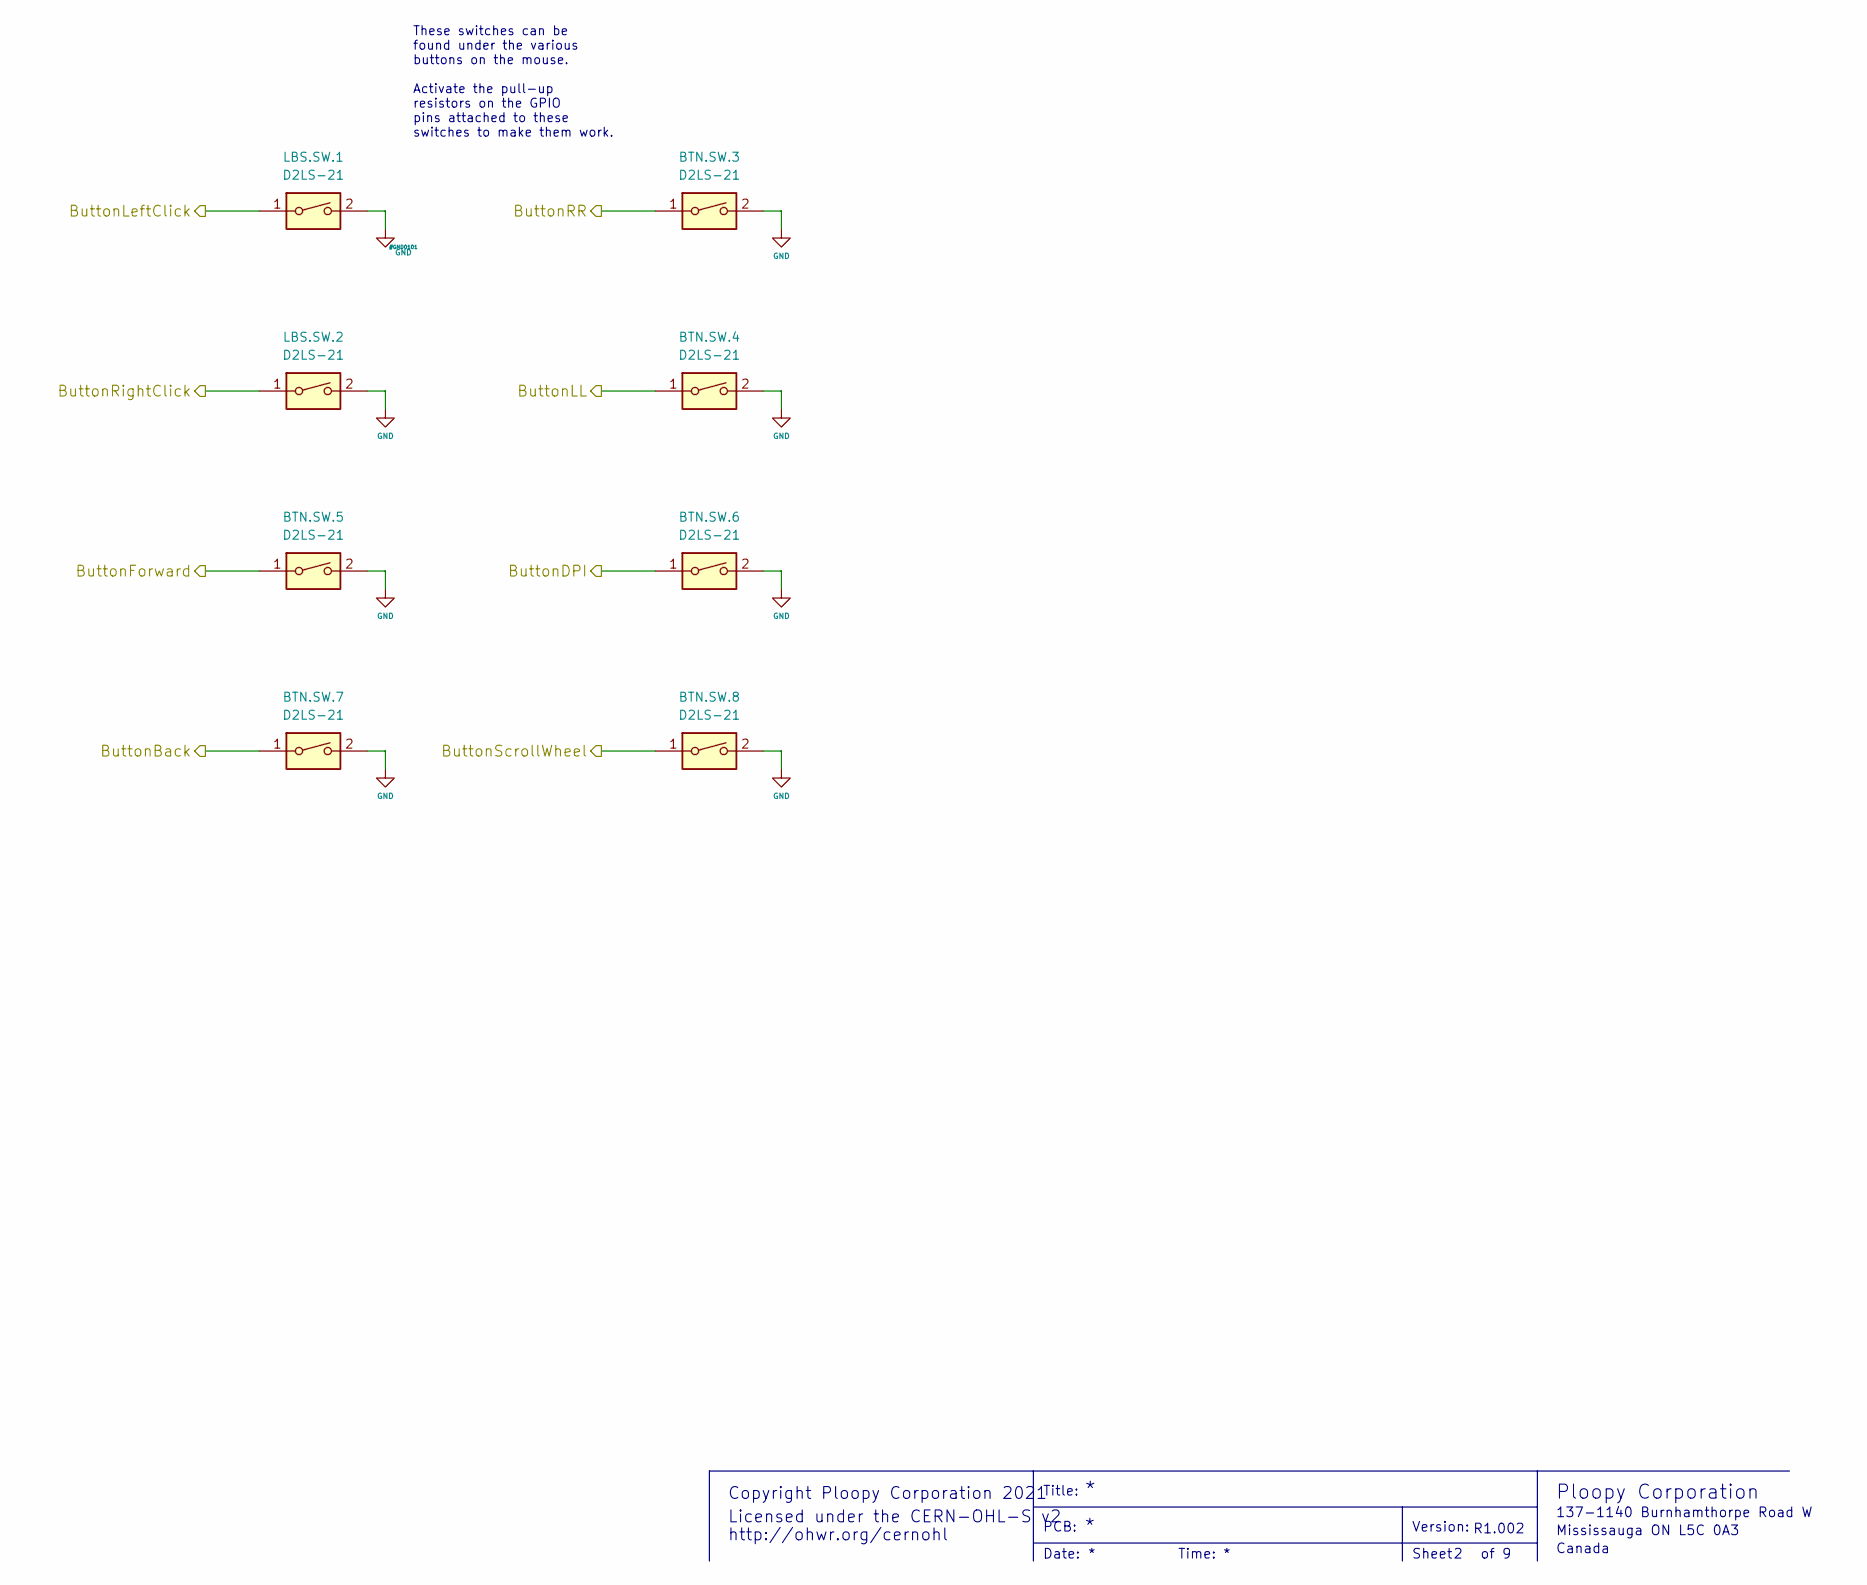
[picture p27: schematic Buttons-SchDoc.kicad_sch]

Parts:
BTN.SW.3, BTN.SW.4, BTN.SW.5, BTN.SW.6, BTN.SW.7, BTN.SW.8: D2LS-21
LBS.SW.1, LBS.SW.2: D2LS-21

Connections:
/BTN/ButtonBack: BTN.SW.7.1; also elsewhere on the board
/BTN/ButtonDPI: BTN.SW.6.1; also elsewhere on the board
/BTN/ButtonForward: BTN.SW.5.1; also elsewhere on the board
/BTN/ButtonLL: BTN.SW.4.1; also elsewhere on the board
/BTN/ButtonLeftClick: LBS.SW.1.1; also elsewhere on the board
/BTN/ButtonRR: BTN.SW.3.1; also elsewhere on the board
/BTN/ButtonRightClick: LBS.SW.2.1; also elsewhere on the board
/BTN/ButtonScrollWheel: BTN.SW.8.1; also elsewhere on the board
GND: BTN.SW.3.2, BTN.SW.4.2, BTN.SW.5.2, BTN.SW.6.2, BTN.SW.7.2, BTN.SW.8.2, LBS.SW.1.2, LBS.SW.2.2; also elsewhere on the board

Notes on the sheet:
Canada
PCB:
137-1140 Burnhamthorpe Road W
http://ohwr.org/cernohl
Copyright Ploopy Corporation 2021
Sheet
Title:
Mississauga ON L5C 0A3
These switches can be found under the various buttons on the mouse. Activate the pull-up resistors on the GPIO pins attached to these switches to make them work.
Version:
Ploopy Corporation
Licensed under the CERN-OHL-S v2
Time:
Date:
R1.002

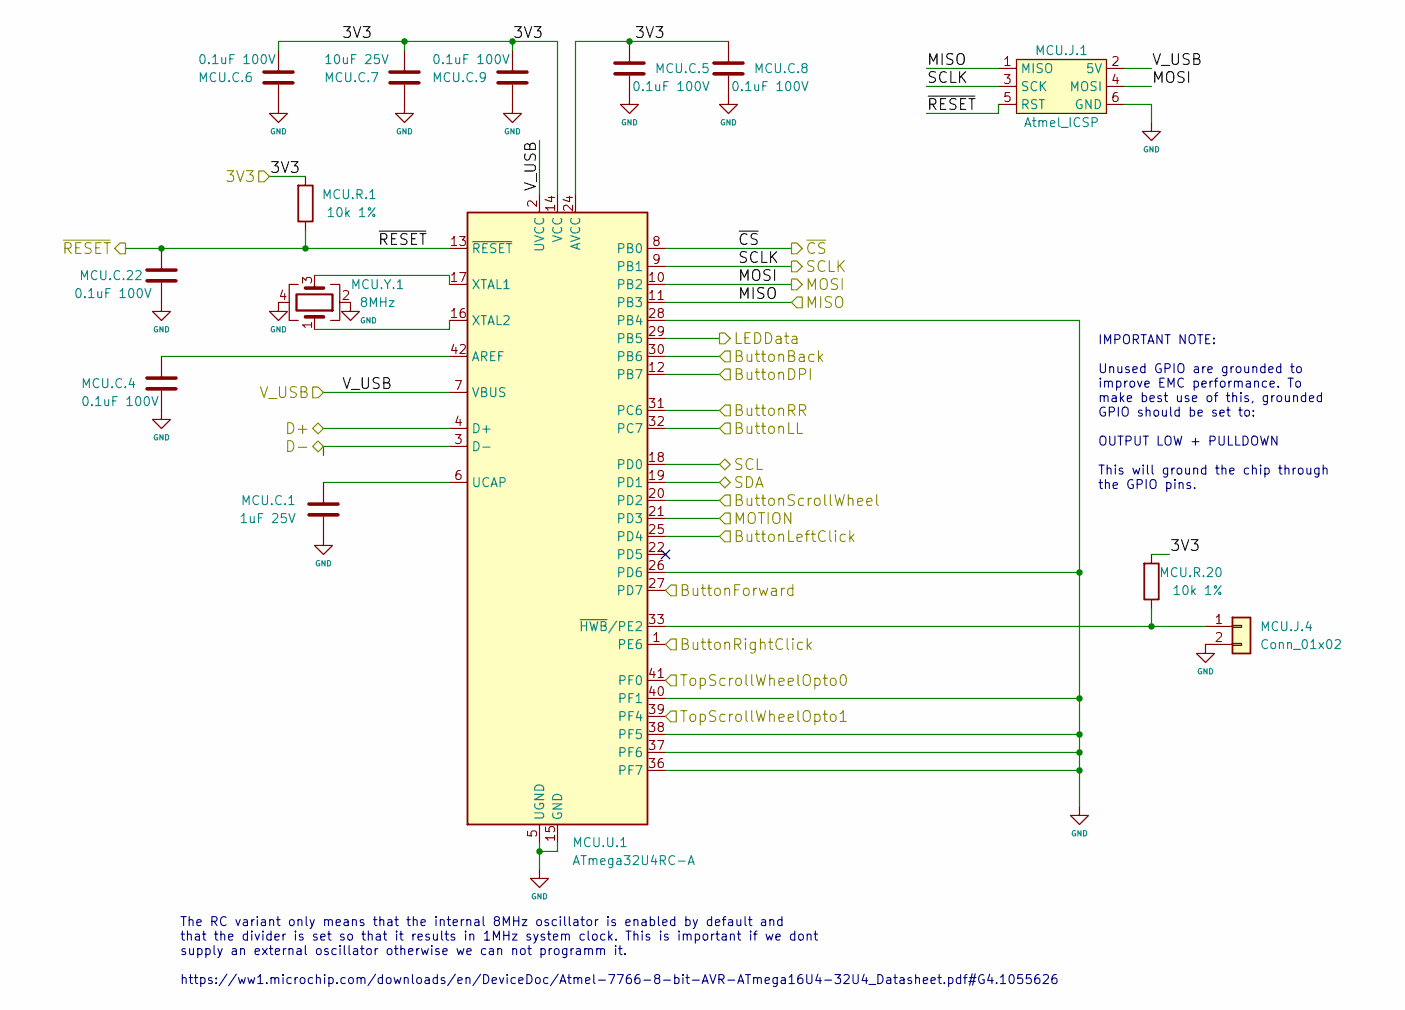
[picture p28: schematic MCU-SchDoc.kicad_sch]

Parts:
MCU.C.1: 1uF 25V; C_0805
MCU.C.4, MCU.C.5, MCU.C.6, MCU.C.8, MCU.C.9, MCU.C.22: 0.1uF 100V; C_0805
MCU.C.7: 10uF 25V; C_0805
MCU.J.1: Atmel_ICSP; 6x2
MCU.J.4: Conn_01x02; 2x1
MCU.R.1, MCU.R.20: 10k 1%; 0805
MCU.U.1: ATmega32U4RC-A; ATMEGA32U4 - TQFP80P1200X1200X120-44N
MCU.Y.1: 8MHz; LFXTAL055663BULK

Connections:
/BTN/ButtonBack: MCU.U.1.30 (PB6); also elsewhere on the board
/BTN/ButtonDPI: MCU.U.1.12 (PB7); also elsewhere on the board
/BTN/ButtonForward: MCU.U.1.27 (PD7); also elsewhere on the board
/BTN/ButtonLL: MCU.U.1.32 (PC7); also elsewhere on the board
/BTN/ButtonLeftClick: MCU.U.1.25 (PD4); also elsewhere on the board
/BTN/ButtonRR: MCU.U.1.31 (PC6); also elsewhere on the board
/BTN/ButtonRightClick: MCU.U.1.1 (PE6); also elsewhere on the board
/BTN/ButtonScrollWheel: MCU.U.1.20 (PD2); also elsewhere on the board
/LED/LEDData: MCU.U.1.29 (PB5); also elsewhere on the board
/LED/V_USB: MCU.J.1.2 (5V), MCU.U.1.2 (UVCC), MCU.U.1.7 (VBUS); also elsewhere on the board
/MCU/3V3: MCU.C.5.2, MCU.C.6.2, MCU.C.7.2, MCU.C.8.2, MCU.C.9.2, MCU.R.1.2, MCU.R.20.2, MCU.U.1.14 (VCC), MCU.U.1.24 (AVCC), MCU.U.1.34 (VCC), MCU.U.1.44 (AVCC); also elsewhere on the board
/MCU/D+: MCU.U.1.4 (D+); also elsewhere on the board
/MCU/D-: MCU.U.1.3 (D-); also elsewhere on the board
/MCU/MISO: MCU.J.1.1 (MISO), MCU.U.1.11 (PB3); also elsewhere on the board
/MCU/MOSI: MCU.J.1.4 (MOSI), MCU.U.1.10 (PB2); also elsewhere on the board
/MCU/MOTION: MCU.U.1.21 (PD3); also elsewhere on the board
/MCU/SCL: MCU.U.1.18 (PD0); also elsewhere on the board
/MCU/SCLK: MCU.J.1.3 (SCK), MCU.U.1.9 (PB1); also elsewhere on the board
/MCU/SDA: MCU.U.1.19 (PD1); also elsewhere on the board
/MCU/TopScrollWheelOpto0: MCU.U.1.41 (PF0); also elsewhere on the board
/MCU/TopScrollWheelOpto1: MCU.U.1.39 (PF4); also elsewhere on the board
/MCU/~CS: MCU.U.1.8 (PB0); also elsewhere on the board
/MCU/~RESET: MCU.C.22.2, MCU.J.1.5 (RST), MCU.R.1.1, MCU.U.1.13 (~RESET); also elsewhere on the board
GND: MCU.C.1.1, MCU.C.4.1, MCU.C.5.1, MCU.C.6.1, MCU.C.7.1, MCU.C.8.1, MCU.C.9.1, MCU.C.22.1, MCU.J.1.6 (GND), MCU.J.4.2, MCU.U.1.5 (UGND), MCU.U.1.15 (GND), MCU.U.1.23 (GND), MCU.U.1.26 (PD6), MCU.U.1.28 (PB4), MCU.U.1.35 (GND), MCU.U.1.36 (PF7), MCU.U.1.37 (PF6), MCU.U.1.38 (PF5), MCU.U.1.40 (PF1), MCU.U.1.43 (GND), MCU.Y.1.2, MCU.Y.1.4; also elsewhere on the board
unnamed: MCU.C.1.2, MCU.U.1.6 (UCAP)
unnamed: MCU.C.4.2, MCU.U.1.42 (AREF)
unnamed: MCU.J.4.1, MCU.R.20.1, MCU.U.1.33 (~HWB/PE2)
unnamed: MCU.U.1.16 (XTAL2), MCU.Y.1.1
unnamed: MCU.U.1.17 (XTAL1), MCU.Y.1.3

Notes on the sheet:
The RC variant only means that the internal 8MHz oscillator is enabled by default and that the divider is set so that it results in 1MHz system clock. This is important if we dont supply an external oscillator otherwise we can not programm it. https://ww1.microchip.com/downloads/en/DeviceDoc/Atmel-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
IMPORTANT NOTE: Unused GPIO are grounded to improve EMC performance. To make best use of this, grounded GPIO should be set to: OUTPUT LOW + PULLDOWN This will ground the chip through the GPIO pins.

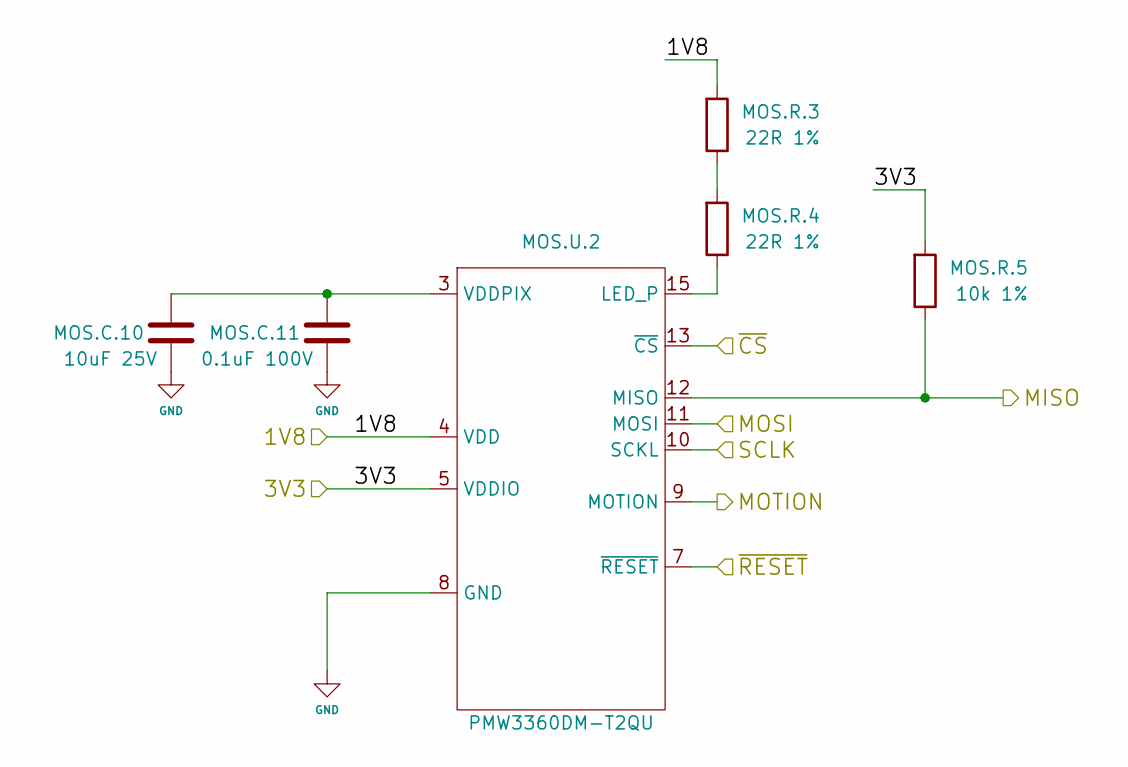
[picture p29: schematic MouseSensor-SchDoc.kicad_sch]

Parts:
MOS.C.10: 10uF 25V; C_0805
MOS.C.11: 0.1uF 100V; C_0805
MOS.R.3, MOS.R.4: 22R 1%; 0805
MOS.R.5: 10k 1%; 0805
MOS.U.2: PMW3360DM-T2QU

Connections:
/MCU/3V3: MOS.R.5.2, MOS.U.2.5 (VDDIO); also elsewhere on the board
/MCU/MISO: MOS.R.5.1, MOS.U.2.12 (MISO); also elsewhere on the board
/MCU/MOSI: MOS.U.2.11 (MOSI); also elsewhere on the board
/MCU/MOTION: MOS.U.2.9 (MOTION); also elsewhere on the board
/MCU/SCLK: MOS.U.2.10 (SCKL); also elsewhere on the board
/MCU/~CS: MOS.U.2.13 (~CS); also elsewhere on the board
/MCU/~RESET: MOS.U.2.7 (~RESET); also elsewhere on the board
/MOS/1V8: MOS.R.3.2, MOS.U.2.4 (VDD); also elsewhere on the board
GND: MOS.C.10.1, MOS.C.11.1, MOS.U.2.8 (GND); also elsewhere on the board
unnamed: MOS.C.10.2, MOS.C.11.2, MOS.U.2.3 (VDDPIX)
unnamed: MOS.R.3.1, MOS.R.4.2
unnamed: MOS.R.4.1, MOS.U.2.15 (LED_P)

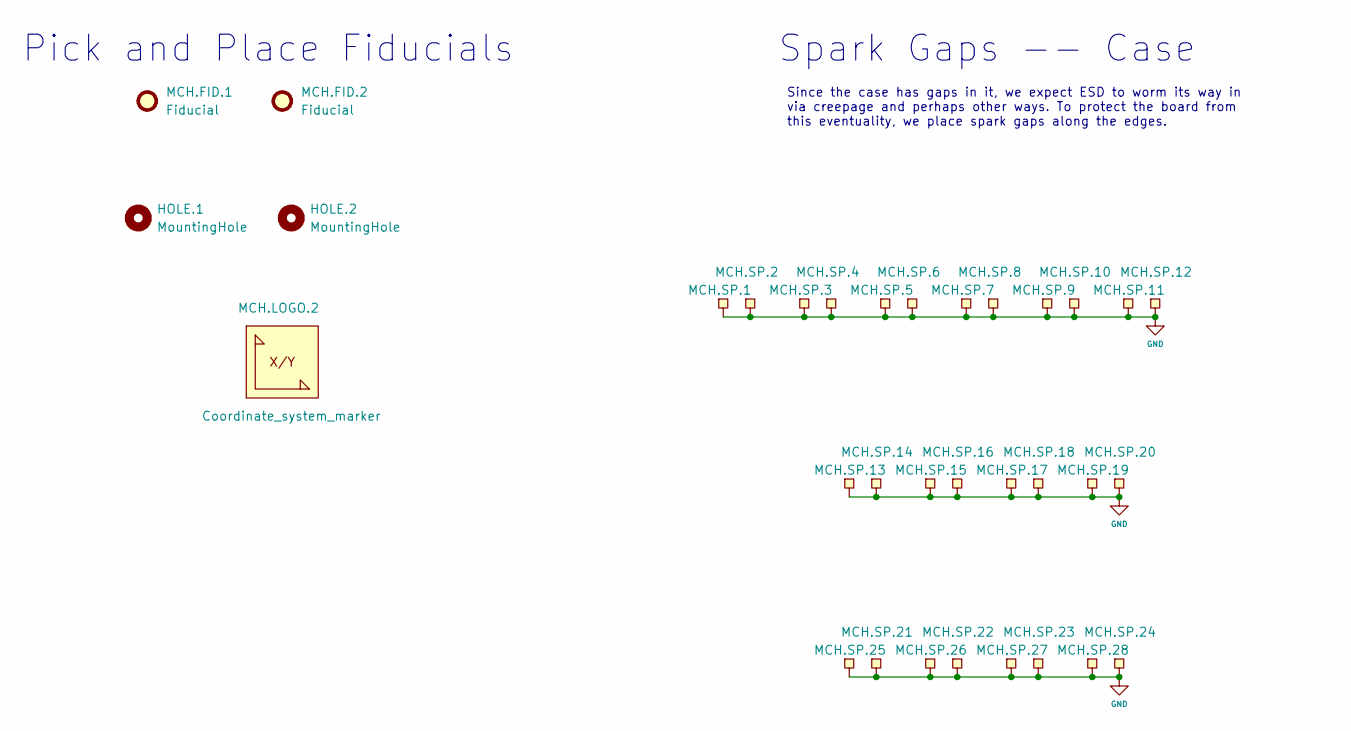
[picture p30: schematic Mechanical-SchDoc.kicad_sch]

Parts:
HOLE.1, HOLE.2: MountingHole
MCH.FID.1, MCH.FID.2: Fiducial; FIDUCIAL_1.5
MCH.LOGO.2: Coordinate_system_marker; Coordinate System
MCH.SP.1, MCH.SP.2, MCH.SP.3, MCH.SP.4, MCH.SP.5, MCH.SP.6, MCH.SP.7, MCH.SP.8, MCH.SP.9, MCH.SP.10, MCH.SP.11, MCH.SP.12, MCH.SP.13, MCH.SP.14, MCH.SP.15, MCH.SP.16, MCH.SP.17, MCH.SP.18, MCH.SP.19, MCH.SP.20, MCH.SP.21, MCH.SP.22, MCH.SP.23, MCH.SP.24, MCH.SP.25, MCH.SP.26, MCH.SP.27, MCH.SP.28: Spark_gap; SparkGap

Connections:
GND: MCH.SP.1.1, MCH.SP.2.1, MCH.SP.3.1, MCH.SP.4.1, MCH.SP.5.1, MCH.SP.6.1, MCH.SP.7.1, MCH.SP.8.1, MCH.SP.9.1, MCH.SP.10.1, MCH.SP.11.1, MCH.SP.12.1, MCH.SP.13.1, MCH.SP.14.1, MCH.SP.15.1, MCH.SP.16.1, MCH.SP.17.1, MCH.SP.18.1, MCH.SP.19.1, MCH.SP.20.1, MCH.SP.21.1, MCH.SP.22.1, MCH.SP.23.1, MCH.SP.24.1, MCH.SP.25.1, MCH.SP.26.1, MCH.SP.27.1, MCH.SP.28.1; also elsewhere on the board

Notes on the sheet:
Spark Gaps -- Case
Since the case has gaps in it, we expect ESD to worm its way in via creepage and perhaps other ways. To protect the board from this eventuality, we place spark gaps along the edges.
Pick and Place Fiducials

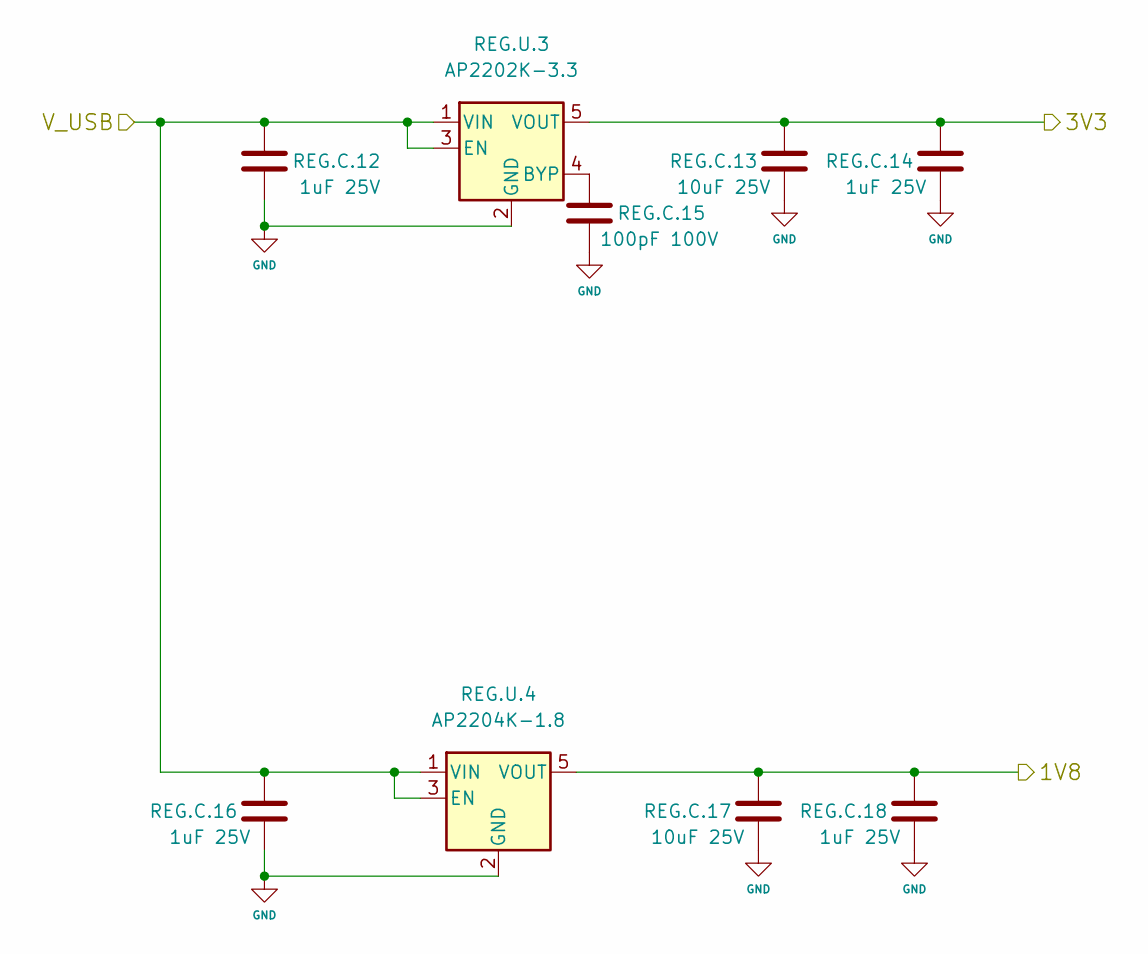
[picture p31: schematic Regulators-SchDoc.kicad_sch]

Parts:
REG.C.12, REG.C.14, REG.C.16, REG.C.18: 1uF 25V; C_0805
REG.C.13, REG.C.17: 10uF 25V; C_0805
REG.C.15: 100pF 100V; C_0805
REG.U.3: AP2202K-3.3; AP2202 - SOT95P270X145-5N
REG.U.4: AP2204K-1.8; AP2202 - SOT95P270X145-5N

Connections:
/LED/V_USB: REG.C.12.2, REG.C.16.2, REG.U.3.1 (VIN), REG.U.3.3 (EN), REG.U.4.1 (VIN), REG.U.4.3 (EN); also elsewhere on the board
/MCU/3V3: REG.C.13.2, REG.C.14.2, REG.U.3.5 (VOUT); also elsewhere on the board
/MOS/1V8: REG.C.17.2, REG.C.18.2, REG.U.4.5 (VOUT); also elsewhere on the board
GND: REG.C.12.1, REG.C.13.1, REG.C.14.1, REG.C.15.1, REG.C.16.1, REG.C.17.1, REG.C.18.1, REG.U.3.2 (GND), REG.U.4.2 (GND); also elsewhere on the board
unnamed: REG.C.15.2, REG.U.3.4 (BYP)

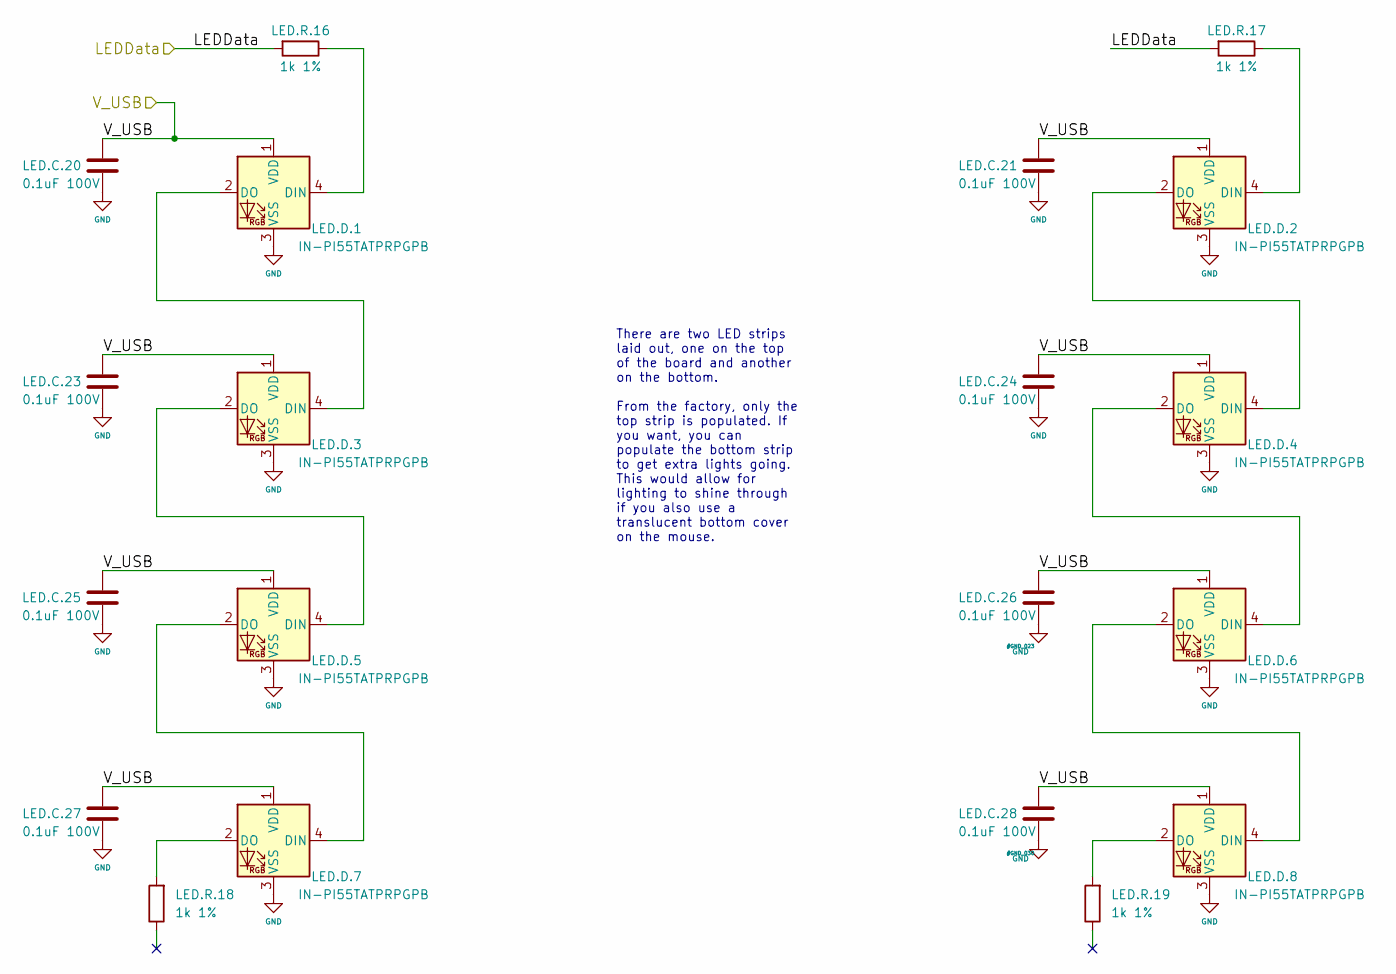
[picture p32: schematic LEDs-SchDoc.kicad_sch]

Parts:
LED.C.20, LED.C.21, LED.C.23, LED.C.24, LED.C.25, LED.C.26, LED.C.27, LED.C.28: 0.1uF 100V; C_0805
LED.D.1, LED.D.2, LED.D.3, LED.D.4, LED.D.5, LED.D.6, LED.D.7, LED.D.8: IN-PI55TATPRPGPB
LED.R.16, LED.R.17, LED.R.18, LED.R.19: 1k 1%; 0805

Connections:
/LED/LEDData: LED.R.16.2, LED.R.17.2; also elsewhere on the board
/LED/V_USB: LED.C.20.2, LED.C.21.2, LED.C.23.2, LED.C.24.2, LED.C.25.2, LED.C.26.2, LED.C.27.2, LED.C.28.2, LED.D.1.1 (VDD), LED.D.2.1 (VDD), LED.D.3.1 (VDD), LED.D.4.1 (VDD), LED.D.5.1 (VDD), LED.D.6.1 (VDD), LED.D.7.1 (VDD), LED.D.8.1 (VDD); also elsewhere on the board
GND: LED.C.20.1, LED.C.21.1, LED.C.23.1, LED.C.24.1, LED.C.25.1, LED.C.26.1, LED.C.27.1, LED.C.28.1, LED.D.1.3 (VSS), LED.D.2.3 (VSS), LED.D.3.3 (VSS), LED.D.4.3 (VSS), LED.D.5.3 (VSS), LED.D.6.3 (VSS), LED.D.7.3 (VSS), LED.D.8.3 (VSS); also elsewhere on the board
unnamed: LED.D.1.2 (DO), LED.D.3.4 (DIN)
unnamed: LED.D.1.4 (DIN), LED.R.16.1
unnamed: LED.D.2.2 (DO), LED.D.4.4 (DIN)
unnamed: LED.D.2.4 (DIN), LED.R.17.1
unnamed: LED.D.3.2 (DO), LED.D.5.4 (DIN)
unnamed: LED.D.4.2 (DO), LED.D.6.4 (DIN)
unnamed: LED.D.5.2 (DO), LED.D.7.4 (DIN)
unnamed: LED.D.6.2 (DO), LED.D.8.4 (DIN)
unnamed: LED.D.7.2 (DO), LED.R.18.2
unnamed: LED.D.8.2 (DO), LED.R.19.2

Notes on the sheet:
There are two LED strips laid out, one on the top of the board and another on the bottom. From the factory, only the top strip is populated. If you want, you can populate the bottom strip to get extra lights going. This would allow for lighting to shine through if you also use a translucent bottom 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

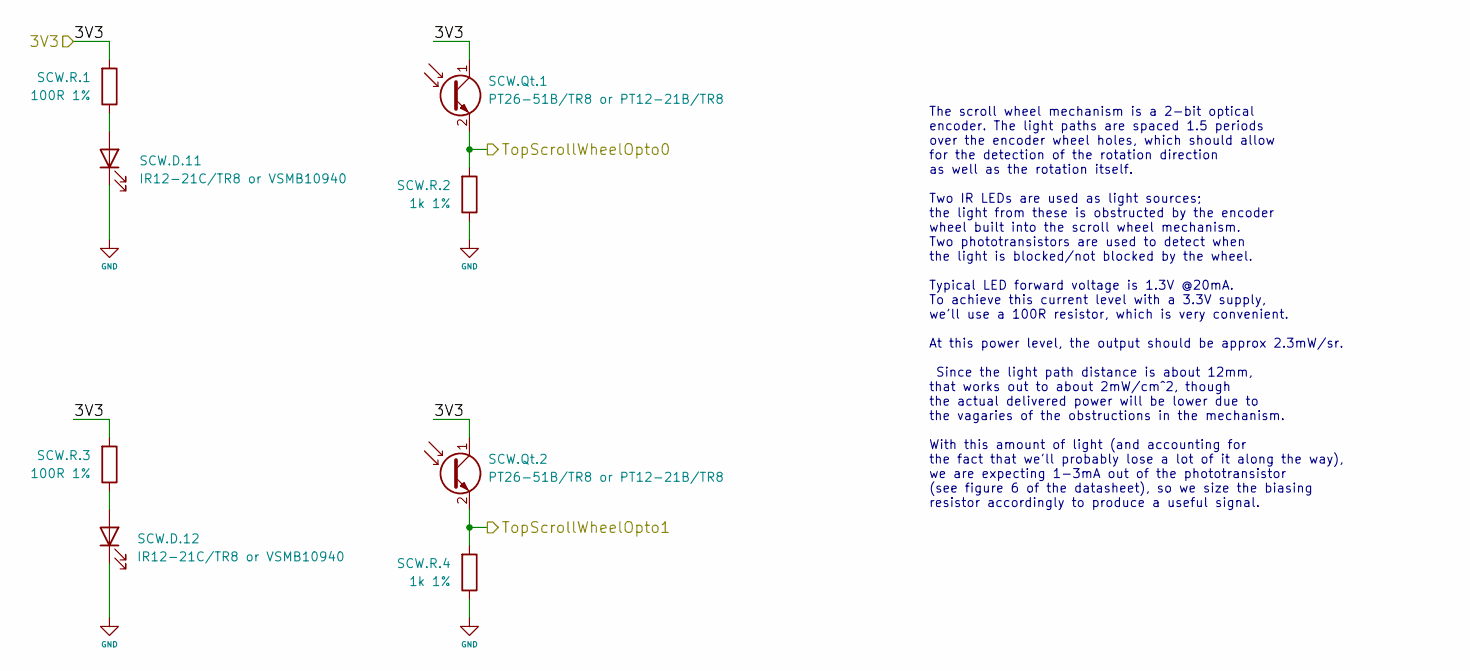
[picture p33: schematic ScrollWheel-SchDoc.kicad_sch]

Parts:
SCW.D.11, SCW.D.12: IR12-21C/TR8 or VSMB10940; IR12-21C-TR8
SCW.Qt.1, SCW.Qt.2: PT26-51B/TR8 or PT12-21B/TR8; PT26-51B-TR8
SCW.R.1, SCW.R.3: 100R 1%; 0805
SCW.R.2, SCW.R.4: 1k 1%; 0805

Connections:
/MCU/3V3: SCW.Qt.1.1 (C), SCW.Qt.2.1 (C), SCW.R.1.2, SCW.R.3.2; also elsewhere on the board
/MCU/TopScrollWheelOpto0: SCW.Qt.1.2 (E), SCW.R.2.2; also elsewhere on the board
/MCU/TopScrollWheelOpto1: SCW.Qt.2.2 (E), SCW.R.4.2; also elsewhere on the board
GND: SCW.D.11.1 (K), SCW.D.12.1 (K), SCW.R.2.1, SCW.R.4.1; also elsewhere on the board
unnamed: SCW.D.11.2 (A), SCW.R.1.1
unnamed: SCW.D.12.2 (A), SCW.R.3.1

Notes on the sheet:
The scroll wheel mechanism is a 2-bit optical encoder. The light paths are spaced 1.5 periods over the encoder wheel holes, which should allow for the detection of the rotation direction as well as the rotation itself. Two IR LEDs are used as light sources; the light from these is obstructed by the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

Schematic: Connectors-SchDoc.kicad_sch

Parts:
USB.C.19: 10uF 25V; C_0805
USB.FB.1, USB.FB.2, USB.FB.3, USB.FB.4, USB.FB.5: ACML-0805-601-T; 0805
USB.J.2: SJ-43514-SMT-TR
USB.J.3: DX07S016JA1R1500
USB.R.6, USB.R.7, USB.R.10, USB.R.11: 22R 1%; 0805
USB.R.8, USB.R.9, USB.R.12, USB.R.13, USB.R.14, USB.R.15: 10k 1%; 0805
USB.Z.1: IP4220CZ6; PESD3V3S4UD - SOT95P275X110-6N

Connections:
/LED/V_USB: USB.C.19.2, USB.FB.1.2; also elsewhere on the board
/MCU/D+: USB.R.7.2; also elsewhere on the board
/MCU/D-: USB.R.6.2; also elsewhere on the board
/MCU/SCL: USB.R.11.2; also elsewhere on the board
/MCU/SDA: USB.R.10.2; also elsewhere on the board
GND: USB.C.19.1, USB.J.2.4 (R2), USB.J.3.1 (GND), USB.J.3.12 (GND), USB.J.3.SHELL (SHIELD), USB.R.12.1, USB.R.13.1, USB.R.14.1, USB.R.15.1, USB.Z.1.2; also elsewhere on the board
unnamed: USB.FB.1.1, USB.J.2.1 (S), USB.J.3.2 (VBUS), USB.J.3.11 (VBUS), USB.R.8.2, USB.R.9.2, USB.Z.1.5
unnamed: USB.FB.2.1, USB.J.3.5 (D-), USB.J.3.8 (D-), USB.Z.1.3
unnamed: USB.FB.2.2, USB.R.6.1
unnamed: USB.FB.3.1, USB.J.3.6 (D+), USB.J.3.7 (D+), USB.Z.1.1
unnamed: USB.FB.3.2, USB.R.7.1
unnamed: USB.FB.4.1, USB.J.2.3 (R1), USB.R.9.1, USB.Z.1.4
unnamed: USB.FB.4.2, USB.R.10.1
unnamed: USB.FB.5.1, USB.J.2.2 (T), USB.R.8.1, USB.Z.1.6
unnamed: USB.FB.5.2, USB.R.11.1
unnamed: USB.J.3.3 (CC1), USB.R.14.2, USB.R.15.2
unnamed: USB.J.3.9 (CC2), USB.R.12.2, USB.R.13.2

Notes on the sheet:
Everyone recommends we add 10uF of capacitance to the 5V input of the USB port, so we'll do that.
Series resistors and 600Ohm ferrite beads on the I2C lines provide some protection against shorts to 5V/GND as well as ESD/EMI.
Since we hide the USB traces sandwiched between ground planes, it makes a lot of sense to make the ground planes of the PCB continuous with the cable shield.
To properly identify this device when connecting to a fully functional USB3.0 upstream device, the CC pins must be pulled down with a "5.1k" resistor. Here, 5k will do to simplify the BoM. The SBU pins in this application are unused, but perhaps in a future version they could be used to transport I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
Here we provide spaces for pull-up resistors on the I2C lines. A relatively large 10k would work well if they're not the only pull-up resistors on the bus.
This neato device protects the mouse from ESD. It should be more than adequate for this relatively tame application.

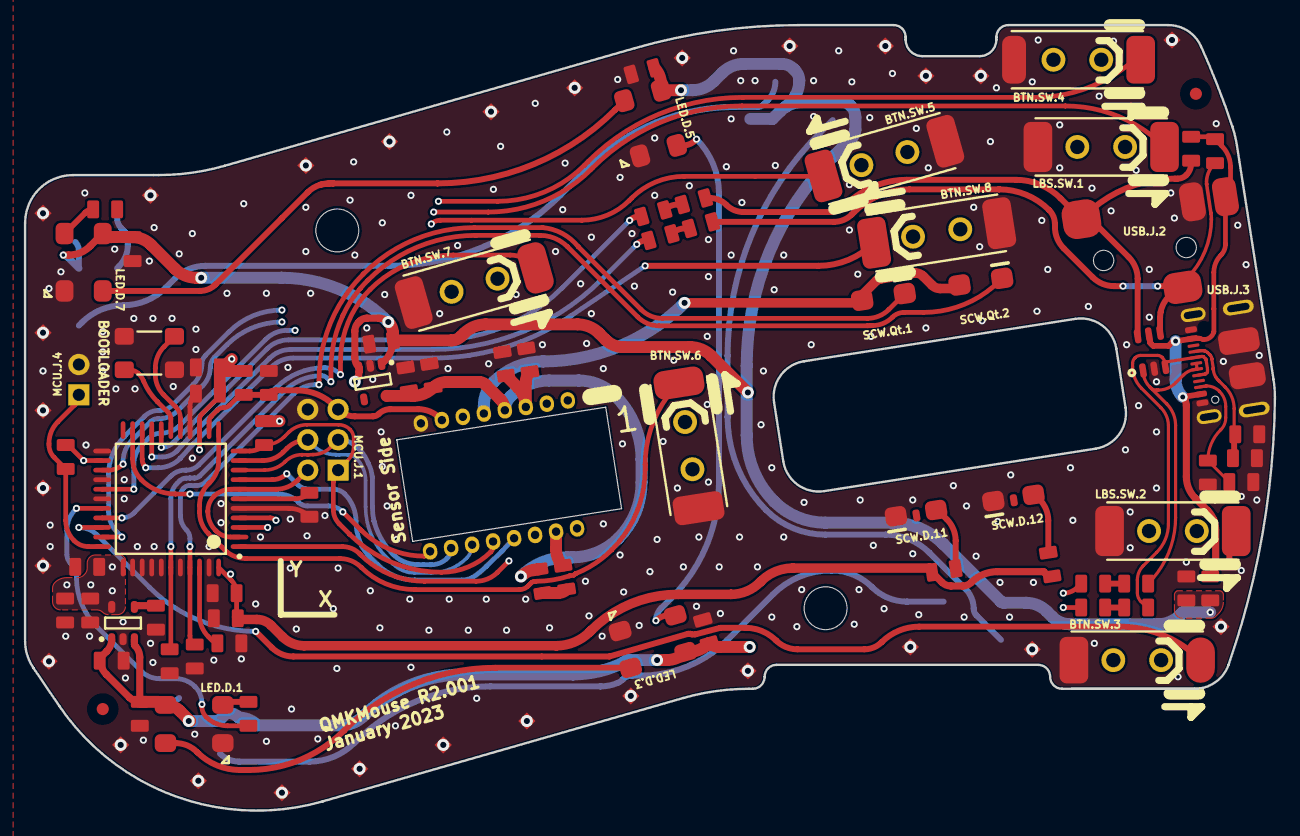
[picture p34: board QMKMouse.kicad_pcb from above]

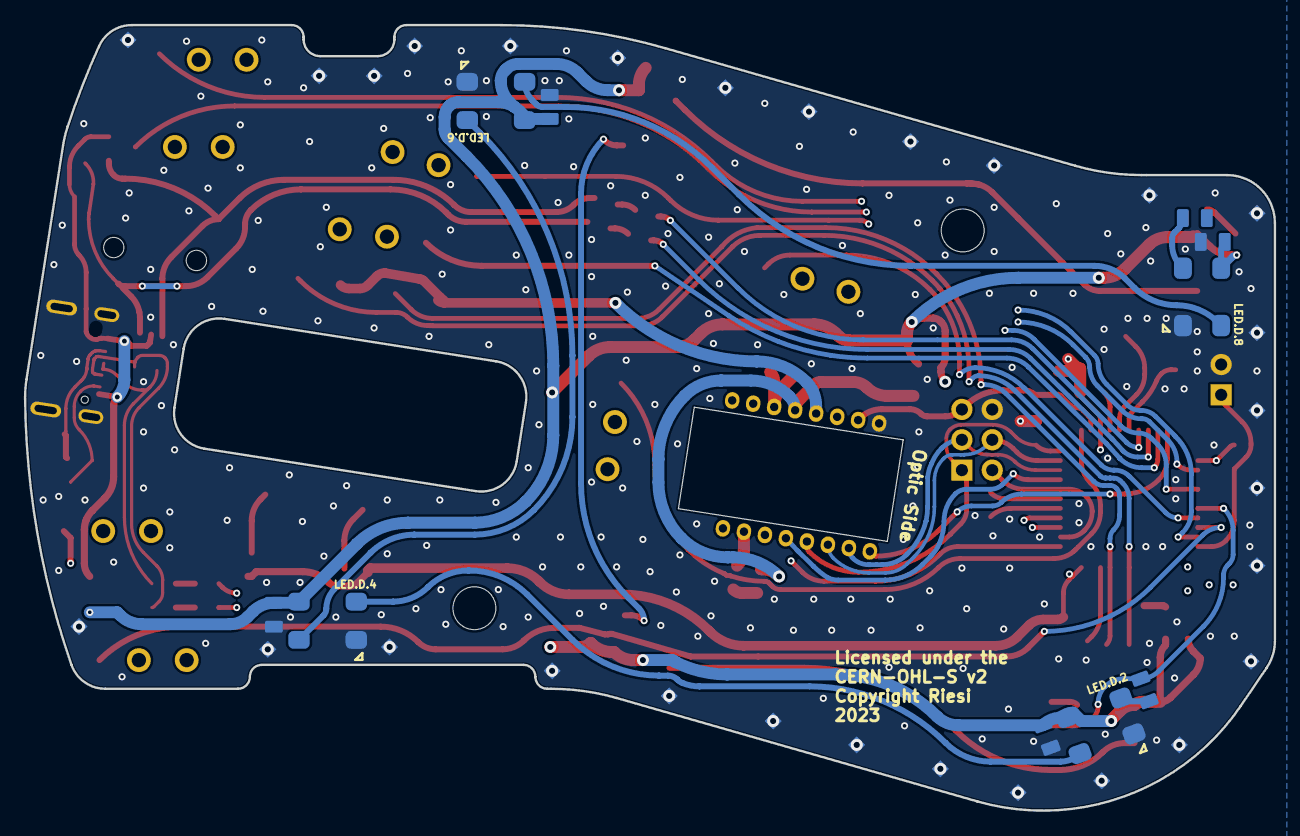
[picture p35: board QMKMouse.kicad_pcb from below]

Board: 4 copper layers, 104.6 x 65.8 mm, 117 parts (10 on the bottom side), 57 nets.

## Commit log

2023-01-18 Port Altium Version to KiCAD; adjust README; resize mouse image
    Here be dragons!
    [Buttons-SchDoc.kicad_sch, Buttons.SchDoc, Chip_Passives.PcbLib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]
2023-01-19 Fix optical sensor cutout; adjust origin and PCB relative to it to match Altium to allow Gerber diffs
    [QMKMouse.kicad_pcb]
2023-01-19 small fix
    [Connectors-SchDoc.kicad_sch, QMKMouse.kicad_pcb]
2023-01-19 Update PCB for better matching; include some comparison Gerber files and diff images; update README
    [QMKMouse-Bottom Layer.gbr, QMKMouse-Bottom Overlay.gbr, QMKMouse-Bottom Paste.gbr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]
2023-01-19 improve edge cuts
    [QMKMouse.kicad_pcb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]
2023-01-19 update schematic components
    [Buttons-SchDoc.kicad_sch, Connectors-SchDoc.kicad_sch, LEDs-SchDoc.kicad_sch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]
2023-01-20 change layer naming
    [Connectors-SchDoc.kicad_sch, QMKMouse.kicad_pcb]
2023-01-20 update schematic from PCB; sync netlist and fix some symbol orientations; also fix LED symbol
    [Buttons-SchDoc.kicad_sch, Connectors-SchDoc.kicad_sch, LEDs-SchDoc.kicad_sch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]
2023-01-20 Fix some schematic PCB mismatch
    [Buttons-SchDoc.kicad_sch, MCU-SchDoc.kicad_sch, Mechanical-SchDoc.kicad_sch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]
2023-01-20 Fix all remaining DRC errors and schematic mismatches
    [Connectors-SchDoc.kicad_sch, LEDs-SchDoc.kicad_sch, Mechanical-SchDoc.kicad_sch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]
2023-01-20 update Schematic
    [LEDs-SchDoc.kicad_sch, MCU-SchDoc.kicad_sch, Mechanical-SchDoc.kicad_sch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]
2023-01-20 fix last sync errors
    [QMKMouse.kicad_pcb, QMKMouse.kicad_sch, ScrollWheel-SchDoc.kicad_sch]
2023-01-20 fix ground connection of LED
    [LEDs-SchDoc.kicad_sch, QMKMouse.kicad_pcb]
2023-01-20 fix ERC errors and use hierarchy labels
    [Buttons-SchDoc.kicad_sch, Connectors-SchDoc.kicad_sch, LEDs-SchDoc.kicad_sch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]
2023-01-20 Fix all ERC errors and replot the schematic
    [Connectors-SchDoc.kicad_sch, QMKMouse.kicad_pcb, QMKMouse.kicad_sch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]
2023-01-20 improve diff validation process
    [QMKMouse-Bottom Layer.gbr, QMKMouse-Bottom Overlay.gbr, QMKMouse-Bottom Paste.gbr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]
2023-01-20 Fix capacitor value and streamline resistor value naming
    [Connectors-SchDoc.kicad_sch, MouseSensor-SchDoc.kicad_sch, QMKMouse.kicad_pcb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]
2023-01-21 fix minor Schematic naming errors; improve BoM generation
    [Buttons-SchDoc.kicad_sch, Connectors-SchDoc.kicad_sch, LEDs-SchDoc.kicad_sch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]
2023-01-21 correct 2 resistor values and further improve BoM (BoM matches Altium BoM now)
    [Connectors-SchDoc.kicad_sch, QMKMouse.kicad_pcb, QMKMouse.kicad_sch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]
2023-01-23 reintroduce 3D models of some components
    [CUI_DEVICES_SJ-43514-SMT-TR.step, D2LS_21.step, K3D-DX07S016JA1-V1_JAE_Proprietary.STEP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]
2023-01-23 import 0805 footprint into its own library to allow assignment of 3d model
    [QMKMouse.kicad_pcb]
2023-01-23 reference 3d model to all components
    [Connectors-SchDoc.kicad_sch, LEDs-SchDoc.kicad_sch, MCU-SchDoc.kicad_sch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]
